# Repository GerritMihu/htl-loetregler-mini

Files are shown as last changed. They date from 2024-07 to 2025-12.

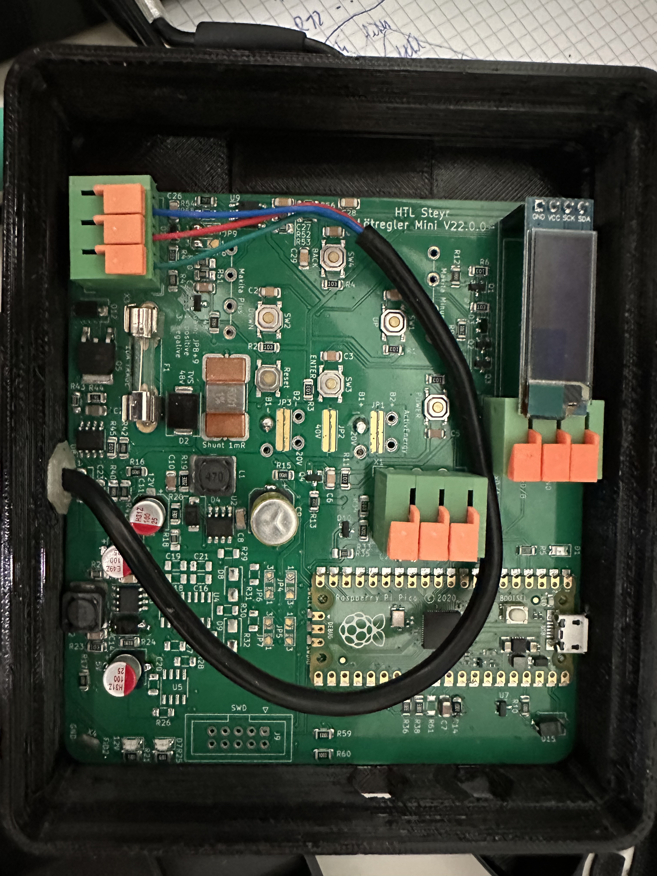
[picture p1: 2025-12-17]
arbeitsanweisungen/Kabel.jpeg

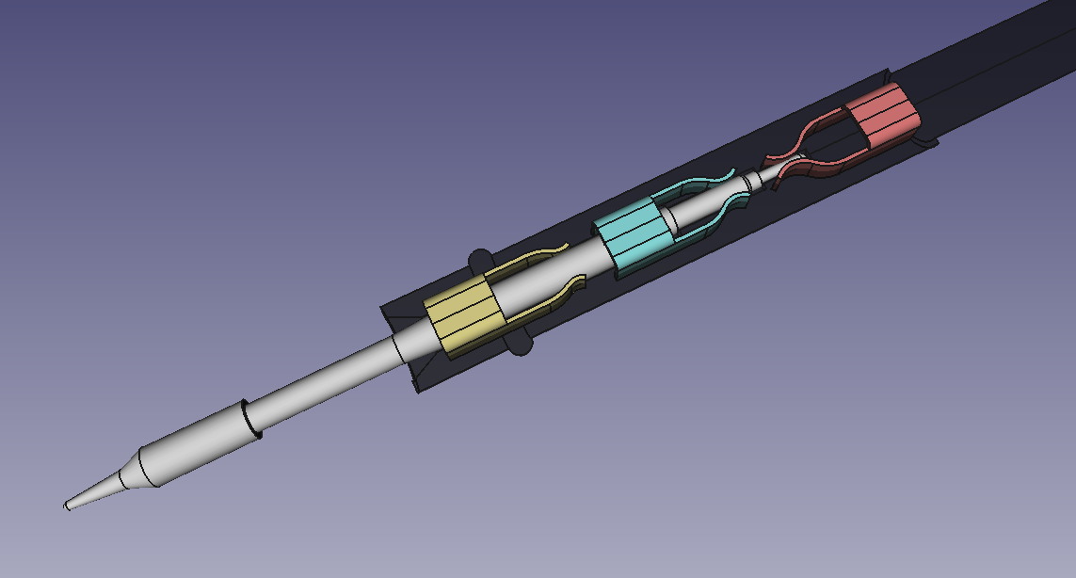
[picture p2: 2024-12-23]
3d/griffstück/screenshot griffstück v1.png

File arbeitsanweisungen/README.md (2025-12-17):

# Lötregler Arbeitsanweisungen

## Vorbereitung

1. Überblick
   1. Hardware
      1. Elektronik
      2. Mechanik
   2. Software
      1. Arduino IDE
      2. Libraries
      3. Das Programm Selbst
   3. Assembling
      1. Zusammenbau
      2. Funktionstest

## Hardware

### Elektronik

1. Stücklisten öffnen
2. Bauteile komissionieren / prüfen
   1. Mengen
   2. Art / Type
   3. Fehlteile
3. Siebdruck
   1. Drucken
   2. Sichtkontrolle / ggf reparatur
4. Bestückung
   1. Bestücken aller Bauteile laut Stückliste
      1. Polaritäten richtig
      2. Werte richtig
      3. Pin 1 bei IC's
   2. Sichtkontrolle / ggf reparatur
5. Reflow
   1. Richtige Temperatur eingestellt
   2. Richtige Temperatur erreicht
   3. Sichtkontrolle / ggf reparatur
6. Handlöten der THT Bauteile
   1. Bauteil bestücken
   2. Bauteil fixieren
   3. Bauteil mit Handlötkolben löten
   4. Sichtkontrolle / ggf reparatur
7. Stecken des Displays
8. Elektrische prüfung der Platine durchführen

### Mechanik

1. Entscheidung welche Variante des Gehäuses gefertigt wird
2. Öffnen der .STL oder .3MF mit einem Slicer
3. Slicen der Dateien als .GCODE
   1. Richtiger Kunststoff
   2. Richtiger Drucker
   3. Stützen an den richtigen Stellen?
   4. Lagenhöhe
   5. Druck Qualität / Geschwindigkeit
4. Transfer der .GCODE Datei auf den Drucker
5. Drucker vorbereiten
   1. Druckbett mit Wasser reinigen
   2. Klebestift auftragen, nur dort wo gedruckt wird
   3. Kunststoff richtig eingespannt
      1. keine Knoten in Fillament
      2. richtiger Kunstoff
      3. Rolle läuft frei / leichtgängig
6. Druck starten
   1. Erste Lage auf Offensichtliche Fehler inspizieren
7. Teile durch biegen des Druckbettes entfernen (Vorsicht heiß)
8. Druckbett reinigen
9. Stützen entfernen

## Software

1. Arduino IDE vorbereiten
   1. Libraries installieren
      1. Sketch ==> Bibliotek einbinden ==> Bibliothek verwalten
      2. Alle Libs aus der #Include einbinden
   2. MCU installieren
      1. Werkzeuge ==>  Board ==> Boardverwalter ==> Raspberry Pico RP2040
2. Code anpassen
   1. Namen Eintragen
   2. Software den eigenen Vorstellungen anpassen
3. Überprüfen drücken
   1. Fehler beheben
4. Leiterplatte mit PC verbinden
5. Upload drücken

## Assembling

1. Elektronik auf Grundplatte
2. Rahmen raufstecken
3. Akkuschuh anschweißen
4. Handstück vorbereiten
5. Hansstück anschließen
6. Zugentlastung
7. Betätiger für Taster einsetzen
8. Deckel montieren
9. Funktionstest mit Testlötspitzen
10. Leistungskalibrierung
11. Have fun...

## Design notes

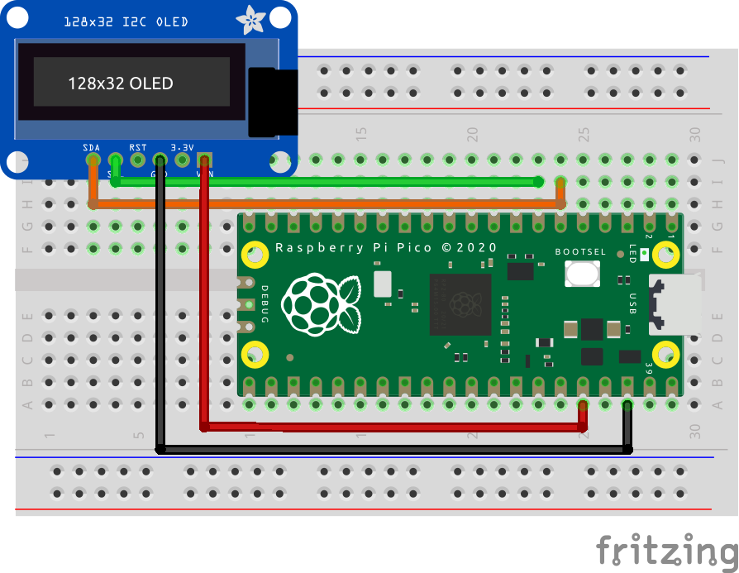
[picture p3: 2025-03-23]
arduino/RP2040/ssd1306_i2c/ssd1306_i2c_bb.png

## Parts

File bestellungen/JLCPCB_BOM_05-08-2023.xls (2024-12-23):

Comment | Designator | Footprint | JLCPCB Part#(optional)
100n/50V | C1 | C_1206_3216Metric | C464972
100n/50V | C2 | C_1206_3216Metric | C464972
100n/50V | C3 | C_1206_3216Metric | C464972
100n/50V | C4 | C_1206_3216Metric | C464972
100n/50V | C16 | C_1206_3216Metric | C464972
100n/50V | C17 | C_1206_3216Metric | C464972
100n/50V | C18 | C_1206_3216Metric | C464972
100n/50V | C19 | C_1206_3216Metric | C464972
100n/50V | C20 | C_1206_3216Metric | C464972
100n/50V | C21 | C_1206_3216Metric | C464972
100n/50V | C22 | C_1206_3216Metric | C464972
100n/50V | C25 | C_1206_3216Metric | C464972
100n/50V | C27 | C_1206_3216Metric | C464972
10n/50V | C6 | C_1206_3216Metric | C525316
10n/50V | C26 | C_1206_3216Metric | C525316
10n/50V | C28 | C_1206_3216Metric | C525316
10n/50V | C29 | C_1206_3216Metric | C525316
100u/25V | C11 | CP_Elec_6.3x5.9 | C320569
100u/25V | C13 | CP_Elec_6.3x5.9 | C320569
100u/25V | C15 | CP_Elec_6.3x5.9 | C320569
10u/16V | C7 | C_1206_3216Metric | C47971
10u/16V | C23 | C_1206_3216Metric | C47971
100n/100V | C8 | C_1206_3216Metric | C1945
100n/100V | C12 | C_1206_3216Metric | C1945
33n/50V | C10 | C_1206_3216Metric | C309052
33n/50V | C14 | C_1206_3216Metric | C309052
1n/100V | C5 | C_1206_3216Metric | C398254
100u/63V | C9 | CP_Elec_8x10 | C487384
1u/100V | C24 | C_1206_3216Metric | C70463
10k | R1 | R_1206_3216Metric | C118075
10k | R2 | R_1206_3216Metric | C118075
10k | R3 | R_1206_3216Metric | C118075
10k | R4 | R_1206_3216Metric | C118075
10k | R6 | R_1206_3216Metric | C118075
10k | R7 | R_1206_3216Metric | C118075
10k | R8 | R_1206_3216Metric | C118075
10k | R11 | R_1206_3216Metric | C118075
10k | R23 | R_1206_3216Metric | C118075
10k | R34 | R_1206_3216Metric | C118075
10k | R45 | R_1206_3216Metric | C118075
10k | R49 | R_1206_3216Metric | C118075
10k | R61 | R_1206_3216Metric | C118075
100R | R18 | R_1206_3216Metric | C245445
100R | R22 | R_1206_3216Metric | C245445
100R | R29 | R_1206_3216Metric | C245445
100R | R30 | R_1206_3216Metric | C245445
100R | R35 | R_1206_3216Metric | C245445
100R | R43 | R_1206_3216Metric | C245445
100R | R50 | R_1206_3216Metric | C245445
100R | R51 | R_1206_3216Metric | C245445
100R | R53 | R_1206_3216Metric | C245445
100R | R55 | R_1206_3216Metric | C245445
100R | R56 | R_1206_3216Metric | C245445
100R | R57 | R_1206_3216Metric | C245445
1k | R5 | R_1206_3216Metric | C104601
1k | R12 | R_1206_3216Metric | C104601
1k | R14 | R_1206_3216Metric | C104601
1k | R27 | R_1206_3216Metric | C104601
1k | R28 | R_1206_3216Metric | C104601
1k | R40 | R_1206_3216Metric | C104601
1k | R41 | R_1206_3216Metric | C104601
1k | R42 | R_1206_3216Metric | C104601
1k | R48 | R_1206_3216Metric | C104601
3k3 | R20 | R_1206_3216Metric | C137292
3k3 | R21 | R_1206_3216Metric | C137292
3k3 | R26 | R_1206_3216Metric | C137292
3k3 | R36 | R_1206_3216Metric | C137292
3k3 | R38 | R_1206_3216Metric | C137292
100k | R10 | R_1206_3216Metric | C269765
100k | R47 | R_1206_3216Metric | C269765
100k | R59 | R_1206_3216Metric | C269765
100k | R60 | R_1206_3216Metric | C269765
22k | R13 | R_1206_3216Metric | R3216-22k
22k | R52 | R_1206_3216Metric | R3216-22k
22k | R54 | R_1206_3216Metric | R3216-22k
1R | R15 | R_1206_3216Metric | C17928
1R | R16 | R_1206_3216Metric | C17928
1R | R17 | R_1206_3216Metric | C17928
10R | R31 | R_1206_3216Metric | R3216-10R
10R | R32 | R_1206_3216Metric | R3216-10R
2k7 | R9 | R_1206_3216Metric | C310343
30k | R19 | R_1206_3216Metric | C137314
6k2 | R24 | R_1206_3216Metric | C323110
680R | R25 | R_1206_3216Metric | C25392
82k | R33 | R_1206_3216Metric | C310365
56k | R44 | R_1206_3216Metric | R3216-56k
1mR/7W/1% | R46 | Shunt-15.2x7.6mm | C481499
47u/1A | L1 | L_7.3x7.3_H4.5_C216198 | C216198
47u/1A | L2 | L_7.3x7.3_H4.5_C216198 | C216198
SS210 | D4 | D_SMA_wide | C2683692
SS210 | D6 | D_SMA_wide | C2683692
SS210 | D11 | D_SMA_wide | C2683692
SS210 | D12 | D_SMA_wide | C2683692
SS210 | D15 | D_SMA_wide | C2683692
BAV99 | D10 | SOT-23 | C2886576
BAV99 | D13 | SOT-23 | C2886576
BAV99 | D14 | SOT-23 | C2886576
grün | D5 | LED_1206_3216Metric | C965825
grün | D7 | LED_1206_3216Metric | C965825
SMAJ8.0CA | D8 | D_SMA | C908814
SMAJ8.0CA | D9 | D_SMA | C908814
rot | D1 | LED_1206_3216Metric | C965823
SMCJ48A | D2 | D_SMC | C310056
3V3 | D3 | SOT-23 | C550950
XL7005A | U2 | SOIC-8-1EP_3.9x4.9mm_P1.27mm_EP2.514x3.2mm_ThermalVias | C50848
XL7005A | U3 | SOIC-8-1EP_3.9x4.9mm_P1.27mm_EP2.514x3.2mm_ThermalVias | C50848
OLED-128x32-Module | U1 | OLED-128x32 | OLED_128x64_white
MAX3232 | U4 | SOIC-16_3.9x9.9mm_P1.27mm | C434486
YD3082EESA | U5 | SOIC-8_3.9x4.9mm_P1.27mm | C269866
LM4040CIM3-3.0/NOPB | U7 | SOT-23 | C132056
TF2101M-TAH | U8 | SOIC-8_3.9x4.9mm_P1.27mm | C2683752
GS8332-SR | U9 | SOIC-8_3.9x4.9mm_P1.27mm | C157713
POWER | X1 | Federklemme_KF142_3P_P5.08mm_C475145 | C80054
COM | X2 | Federklemme_KF142_3P_P5.08mm_C475145 | C80054
Lötkolben | X3 | Federklemme_KF142_3P_P5.08mm_C475145 | C80054
GND-Öse | X4 | Keystone_5016 | C238129
Clip 20x5 | F1 | fuse-clip_20x5mm | C3130
UP | SW1 | SW_Push_5.1mm_H1.5mm | C318884
DOWN | SW2 | SW_Push_5.1mm_H1.5mm | C318884
ENTER | SW3 | SW_Push_5.1mm_H1.5mm | C318884
BACK | SW4 | SW_Push_5.1mm_H1.5mm | C318884
Ein/Aus | SW5 | SW_Push_5.1mm_H1.5mm | C318884
RESET | SW6 | SW_Push_5.1mm_H1.5mm | C318884
MMBT3904 | Q2 | SOT-23 | C382281
MMBT3904 | Q3 | SOT-23 | C382281
Buchsenleiste 4P | Item1 | Virtual-Item | C5176037
Clip 20x5 | Item4 | Virtual-Item | C3130
Sicherung, 5x20, 10A, träge | Item5 | Virtual-Item | C142673
2N7002 | Q1 | SOT-23 | C350313
ZXMP10A13FTA | Q4 | SOT-23 | C50185
KND3508A | Q5 | TO-252-2 | C116513
SWD | J9 | IDC-Header_2x05_P2.54mm_Vertical | C5665

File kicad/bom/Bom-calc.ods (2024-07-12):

null | Sourced | Placed | Inspected | References | Value | Footprint | Datasheet | Description | DistOrderNr | Distributor | Quantity
1 |  |  |  | C1, C2, C3, C4, C22, C25, C27 | 100n/50V | C_1206_3216Metric | https://datasheet.lcsc.com/szlcsc/1811151136_Walsin-Tech-Corp-0603B104K160CT_C80516.pdf |  | C464972 | LCSC | 7
2 |  |  |  | C6, C26, C28, C29 | 10n/50V | C_1206_3216Metric | https://datasheet.lcsc.com/lcsc/2006031834_PSA-Prosperity-Dielectrics-FN31X103K500PXG_C525316.pdf |  | C525316 | LCSC | 4
3 | ✓ |  |  | C11, C13, C15 | 100u/25V | CP_Elec_6.3x5.9 | https://datasheet.lcsc.com/lcsc/1810261549_AISHI-Aihua-Group-SVZ1EM101E06E00RAXXX_C320569.pdf |  | C320569 | LCSC | 3
4 | ✓ |  |  | C7, C23 | 10u/16V | C_1206_3216Metric | https://datasheet.lcsc.com/lcsc/1811151136_Samsung-Electro-Mechanics-CL31B106KOHNNNE_C47971.pdf |  | C47971 | LCSC | 2
5 |  |  |  | C8, C12 | 100n/100V | C_1206_3216Metric | https://datasheet.lcsc.com/lcsc/1810251120_Samsung-Electro-Mechanics-CL31B104KCFNNNE_C1945.pdf |  | C1945 | LCSC | 2
6 |  |  |  | C10, C14 | 33n/50V | C_1206_3216Metric | https://datasheet.lcsc.com/lcsc/1810261112_CCTC-TCC1206X7R333K500DT_C309052.pdf |  | C309052 | LCSC | 2
7 |  |  |  | C5 | 1n/100V | C_1206_3216Metric | https://datasheet.lcsc.com/lcsc/1912111437_IHHEC-HOLY-STONE-ENTERPRISE-CO---LTD-C1206X102K101T_C398254.pdf |  | C398254 | LCSC | 1
8 |  |  |  | C9 | 100u/63V | CP_Elec_8x10 | https://datasheet.lcsc.com/lcsc/2002201612_Ymin-VKMD1001J101MV_C487384.pdf |  | C487384 | LCSC | 1
9 |  |  |  | C24 | 1u/100V | C_1206_3216Metric | https://datasheet.lcsc.com/lcsc/1810241228_YAGEO-CC1206KKX7R0BB105_C70463.pdf |  | C70463 | LCSC | 1
10 |  |  |  | R1, R2, R3, R4, R6, R7, R8, R11, R23, R34, R45, R49 | 10k | R_1206_3216Metric | https://datasheet.lcsc.com/lcsc/1810301936_FH--Guangdong-Fenghua-Advanced-Tech-RS-06K103JT_C118075.pdf |  | C118075 | LCSC | 12
11 |  |  |  | R18, R22, R35, R43, R50, R51, R53, R55, R56, R57 | 100R | R_1206_3216Metric | https://datasheet.lcsc.com/lcsc/1811141436_Ever-Ohms-Tech-CR1206F100RP05Z_C245445.pdf |  | C245445 | LCSC | 10
12 |  |  |  | R5, R12, R14, R40, R41, R42, R48 | 1k | R_1206_3216Metric | https://datasheet.lcsc.com/lcsc/1811081842_RALEC-RTT06102JTP_C104601.pdf |  | C104601 | LCSC | 7
13 |  |  |  | R10, R47, R59, R60 | 100k | R_1206_3216Metric | https://datasheet.lcsc.com/lcsc/1811101612_TyoHM-RMC1206100K1-N_C269765.pdf |  | C269765 | LCSC | 4
14 |  |  |  | R20, R21, R36, R38 | 3k3 | R_1206_3216Metric | https://datasheet.lcsc.com/lcsc/1810241114_YAGEO-AC1206FR-073K3L_C229599.pdf |  | C137292 | LCSC | 4
15 |  |  |  | R13, R52, R54 | 22k | R_1206_3216Metric |  |  | R3216-22k | AufLager | 3
16 |  |  |  | R15, R16, R17 | 1R | R_1206_3216Metric | https://datasheet.lcsc.com/lcsc/2206010145_UNI-ROYAL-Uniroyal-Elec-1206W4F100KT5E_C17928.pdf |  | C17928 | LCSC | 3
17 |  |  |  | R9 | 2k7 | R_1206_3216Metric | https://datasheet.lcsc.com/lcsc/1810311325_FH--Guangdong-Fenghua-Advanced-Tech-RS-06K2701FT_C310343.pdf |  | C310343 | LCSC | 1
18 |  |  |  | R19 | 30k | R_1206_3216Metric | https://datasheet.lcsc.com/lcsc/1810241230_YAGEO-RC1206FR-0730KL_C137314.pdf |  | C137314 | LCSC | 1
19 |  |  |  | R24 | 6k2 | R_1206_3216Metric | https://datasheet.lcsc.com/lcsc/1912111437_FH--Guangdong-Fenghua-Advanced-Tech-RS-06K6191FT_C323110.pdf |  | C323110 | LCSC | 1
20 |  |  |  | R25 | 680R | R_1206_3216Metric | https://datasheet.lcsc.com/lcsc/1810311130_FH--Guangdong-Fenghua-Advanced-Tech-RS-06K681JT_C140005.pdf |  | C25392 | LCSC | 1
21 |  |  |  | R33 | 82k | R_1206_3216Metric | https://datasheet.lcsc.com/lcsc/1810311325_FH--Guangdong-Fenghua-Advanced-Tech-RS-06K8202FT_C310365.pdf |  | C310365 | LCSC | 1
22 |  |  |  | R44 | 56k | R_1206_3216Metric |  |  | R3216-56k | AufLager | 1
23 |  |  |  | R46 | 1mR/7W/1% | Shunt-15.2x7.6mm | https://datasheet.lcsc.com/lcsc/2001071408_Milliohm-HoLRS1575-1mR-1-_C481499.pdf |  | C481499 | LCSC | 1
24 |  |  |  | L1, L2 | 47u/1A | L_7.3x7.3_H4.5_C216198 | https://datasheet.lcsc.com/lcsc/1811131654_Sunltech-Tech-SLH0704S470MTT_C216198.pdf |  | C216198 | LCSC | 2
25 |  |  |  | D4, D6, D11, D12, D15 | SS210 | D_SMA_wide | https://datasheet.lcsc.com/lcsc/2101111838_ZHIDE-SS210A-W_C2683692.pdf |  | C2683692 | LCSC | 5
26 |  |  |  | D10, D13, D14 | BAV99 | SOT-23 | https://assets.nexperia.com/documents/data-sheet/BAV99_SER.pdf |  | C2886576 | LCSC | 3
27 |  |  |  | D5, D7 | grün | LED_1206_3216Metric | https://datasheet.lcsc.com/lcsc/2101041032_XINGLIGHT-XL-3216UGC_C965825.pdf |  | C965825 | LCSC | 2
28 |  |  |  | D1 | rot | LED_1206_3216Metric | https://datasheet.lcsc.com/lcsc/2101041032_XINGLIGHT-XL-3216UOC_C965823.pdf |  | C965823 | LCSC | 1
29 |  |  |  | D2 | SMCJ48A | D_SMC | https://datasheet.lcsc.com/lcsc/1912111437_Brightking-SMCJ48A-TR13_C310056.pdf |  | C310056 | LCSC | 1
30 |  |  |  | D3 | 3V3 | SOT-23 | https://diotec.com/tl_files/diotec/files/pdf/datasheets/bzx84c2v4.pdf |  | C550950 | LCSC | 1
31 |  |  |  | U2, U3 | XL7005A | SOIC-8-1EP_3.9x4.9mm_P1.27mm_EP2.514x3.2mm_ThermalVias | https://datasheet.lcsc.com/lcsc/1811081614_XLSEMI-XL7005A_C50848.pdf |  | C50848 | LCSC | 2
32 |  |  |  | U1 | OLED-128x32-Module | OLED-128x32 |  |  | OLED_128x64_white | AliExpress, SAMIORE Store | 1
33 |  |  |  | U6 | Pico | RPi_Pico_SMD |  |  |  |  | 1
34 |  |  |  | U7 | LM4040CIM3-3.0/NOPB | SOT-23 | http://www.ti.com/lit/ds/symlink/lm4040-n.pdf |  | C132056 | LCSC | 1
35 |  |  |  | U8 | TF2101M-TAH | SOIC-8_3.9x4.9mm_P1.27mm |  |  | C2683752 | LCSC | 1
36 |  |  |  | U9 | GS8332-SR | SOIC-8_3.9x4.9mm_P1.27mm | http://www.ti.com/lit/ds/symlink/lm2904-n.pdf |  | C157713 | LCSC | 1
37 |  |  |  | X1 | POWER | Federklemme_KF142_3P_P5.08mm_C475145 | https://datasheet.lcsc.com/lcsc/2001151504_Cixi-Kefa-Elec-KF142R-5-08-3P_C475145.pdf |  | C80054 | LCSC | 1
38 |  |  |  | X2 | COM | Federklemme_KF142_3P_P5.08mm_C475145 | https://datasheet.lcsc.com/lcsc/2001151504_Cixi-Kefa-Elec-KF142R-5-08-3P_C475145.pdf |  | C80054 | LCSC | 1
39 |  |  |  | X3 | Lötkolben | Federklemme_KF142_3P_P5.08mm_C475145 | https://datasheet.lcsc.com/lcsc/2001151504_Cixi-Kefa-Elec-KF142R-5-08-3P_C475145.pdf |  | C80054 | LCSC | 1
40 |  |  |  | X4 | GND-Öse | Keystone_5016 | https://datasheet.lcsc.com/lcsc/1810151521_Keystone-5016_C238129.pdf |  | C238129 | LCSC | 1
41 |  |  |  | F1 | Clip 20x5 | fuse-clip_20x5mm | https://datasheet.lcsc.com/lcsc/1808311724_Shenzhen-lanson-Elec-LS-502_C182320.pdf |  | C3130 | LCSC | 1
42 |  |  |  | SW1 | UP | SW_Push_5.1mm_H1.5mm | https://datasheet.lcsc.com/lcsc/2002271431_XKB-Connectivity-TS-1187A-B-A-B_C318884.pdf |  | C318884 | LCSC | 1
43 |  |  |  | SW2 | DOWN | SW_Push_5.1mm_H1.5mm | https://datasheet.lcsc.com/lcsc/2002271431_XKB-Connectivity-TS-1187A-B-A-B_C318884.pdf |  | C318884 | LCSC | 1
44 |  |  |  | SW3 | ENTER | SW_Push_5.1mm_H1.5mm | https://datasheet.lcsc.com/lcsc/2002271431_XKB-Connectivity-TS-1187A-B-A-B_C318884.pdf |  | C318884 | LCSC | 1
45 |  |  |  | SW4 | BACK | SW_Push_5.1mm_H1.5mm | https://datasheet.lcsc.com/lcsc/2002271431_XKB-Connectivity-TS-1187A-B-A-B_C318884.pdf |  | C318884 | LCSC | 1
46 |  |  |  | SW5 | Ein/Aus | SW_Push_5.1mm_H1.5mm | https://datasheet.lcsc.com/lcsc/2002271431_XKB-Connectivity-TS-1187A-B-A-B_C318884.pdf |  | C318884 | LCSC | 1
47 |  |  |  | SW6 | RESET | SW_Push_5.1mm_H1.5mm | https://datasheet.lcsc.com/lcsc/2002271431_XKB-Connectivity-TS-1187A-B-A-B_C318884.pdf |  | C318884 | LCSC | 1
48 |  |  |  | JP4, JP5, JP6, JP7 | COM | SolderJumper-3_P2.0mm_Open_TrianglePad1.0x1.5mm_NumberLabels |  |  | NAP | NAP | 4
49 |  |  |  | FID1, FID2 | Fiducial | paste-fiducial | NAP |  | NAP | NAP | 2
50 |  |  |  | JP1, JP3 | 20V | SolderJumper-2_2.2x8mm_Open |  |  | NAP | NAP | 2
51 |  |  |  | JP8, JP9 | OP-Polarität | SolderJumper-3_P2.0mm_Open_TrianglePad1.0x1.5mm_NumberLabels |  |  | NAP | NAP | 2
52 |  |  |  | Q2, Q3 | MMBT3904 | SOT-23 | https://www.fairchildsemi.com/datasheets/2N/2N3904.pdf |  | C382281 | LCSC | 2
53 |  |  |  | Item1 | Buchsenleiste 4P | Virtual-Item |  |  | C5176037 | LCSC | 1
54 |  |  |  | Item2 | Stencil, 120um, 25mm Rand, Edelstahl | Virtual-Item |  |  | Custom1 | Multi-CB | 1
55 |  |  |  | Item3 | PCB, 1 Layer, 35um Cu, 1.6mm, ca. 100x110 | Virtual-Item |  |  | Custom2 | Multi-CB | 1
56 |  |  |  | Item4 | Clip 20x5 | Virtual-Item |  |  | C3130 | LCSC | 1
57 |  |  |  | Item5 | Sicherung, 5x20, 10A, träge | Virtual-Item |  |  | C142673 | LCSC | 1
58 |  |  |  | JP2 | 40V | SolderJumper-2_2.2x8mm_Open |  |  | NAP | NAP | 1
59 |  |  |  | Q1 | 2N7002 | SOT-23 | https://www.fairchildsemi.com/datasheets/2N/2N7002.pdf |  | C350313 | LCSC | 1
60 |  |  |  | Q4 | ZXMP10A13FTA | SOT-23 | http://assets.nexperia.com/documents/data-sheet/BSS84.pdf |  | C50185 | LCSC | 1
61 |  |  |  | Q5 | KND3508A | TO-252-2 | https://datasheet.lcsc.com/lcsc/1811151428_KIA-Semicon-Tech-KND3508A_C116513.pdf |  | C116513 | LCSC | 1
62 |  |  |  | J3, J4 | Makita Plus | Faston_Tab_6.3mm_vertical |  |  | VT FS-P 6,35 | Reichelt | 2
63 |  |  |  | J5, J6 | Makita Minus | Faston_Tab_6.3mm_vertical |  |  | VT FS-P 6,35 | Reichelt | 2
64 |  |  |  | J1 | ActivEnergy B2+ | Faston_Tab_6.3mm_vertical |  |  | VT FS-P 6,35 | Reichelt | 1
65 |  |  |  | J2 | ActivEnergy B1+ | Faston_Tab_6.3mm_vertical |  |  | VT FS-P 6,35 | Reichelt | 1
66 |  |  |  | J7 | ActivEnergy B2- | Faston_Tab_6.3mm_vertical |  |  | VT FS-P 6,35 | Reichelt | 1
67 |  |  |  | J8 | ActivEnergy B1- | Faston_Tab_6.3mm_vertical |  |  | VT FS-P 6,35 | Reichelt | 1

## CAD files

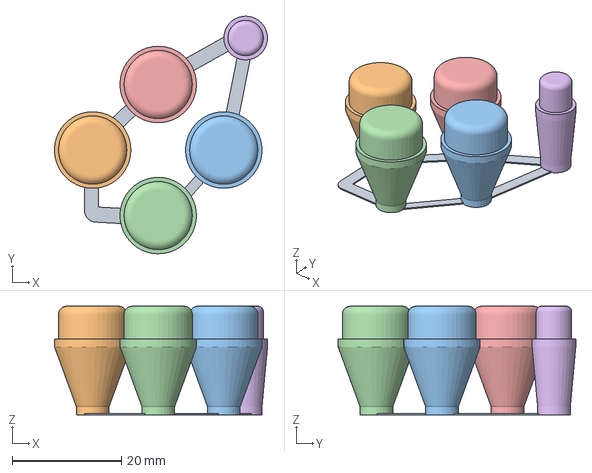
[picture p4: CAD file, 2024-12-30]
3d/gehäuse/Taster_ohne_reset.3mf
39.0 x 43.5 x 19.9 mm

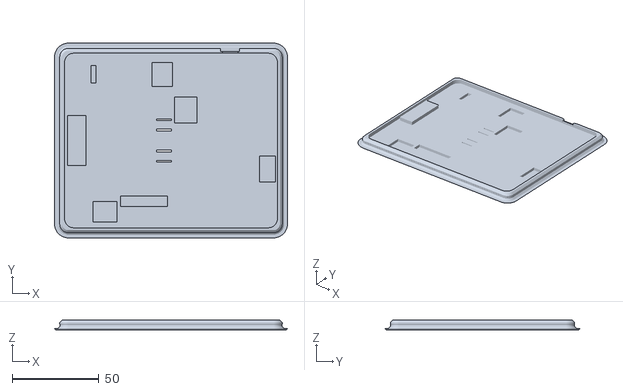
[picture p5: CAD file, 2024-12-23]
3d/gehäuse/lötregler-gehäuse-boden_v4_activEnergy.stl
134.0 x 112.0 x 5.80

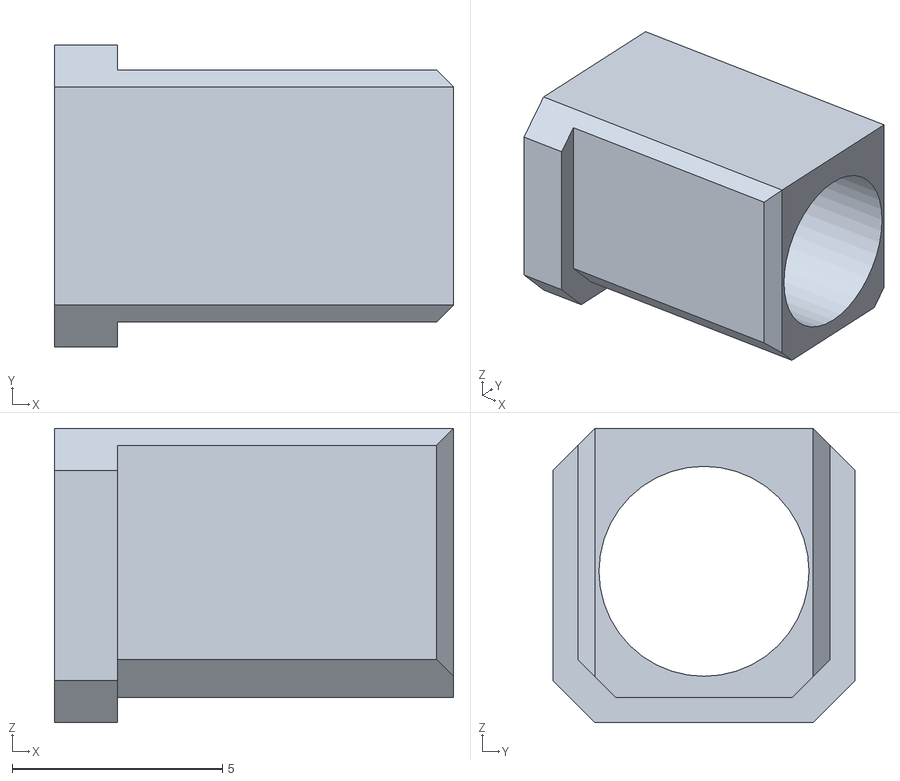
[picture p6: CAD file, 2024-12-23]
3d/griffstück/griffstück_isolator_htc-_h+_v2.2.stl
9.50 x 7.20 x 7.00

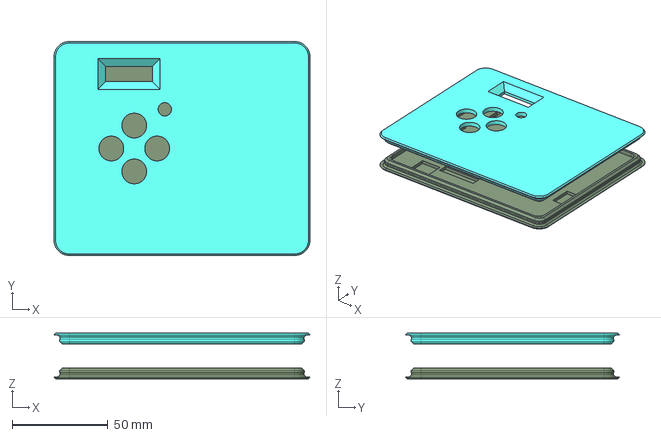
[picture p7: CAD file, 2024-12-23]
3d/gehäuse/lötregler-gehäuse.FCStd
134.0 x 112.0 x 24.0 mm
deckel_v3
Boden_ActivEnergy_v4

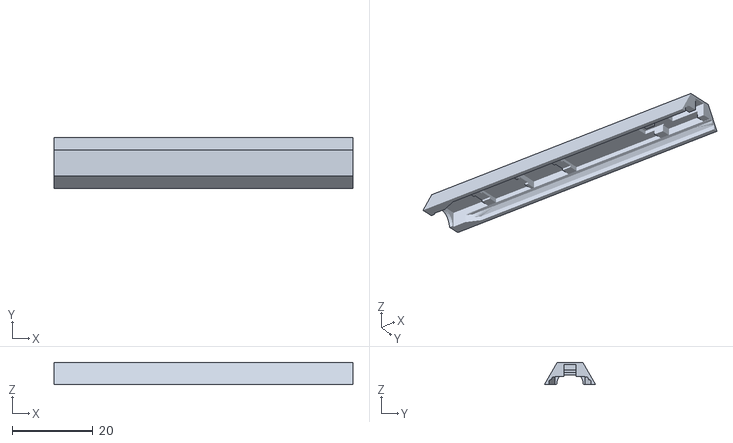
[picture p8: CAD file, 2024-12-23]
3d/griffstück/griffstück_halbschale-hex_v2.stl
74.0 x 12.7 x 5.50

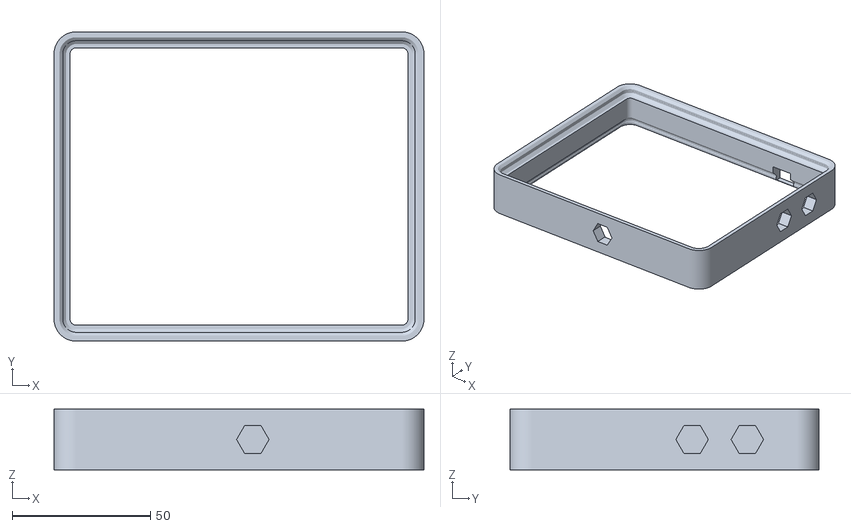
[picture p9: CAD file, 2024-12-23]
3d/gehäuse/lötregler-gehäuse-wand_v3.stl
134.0 x 112.0 x 22.0

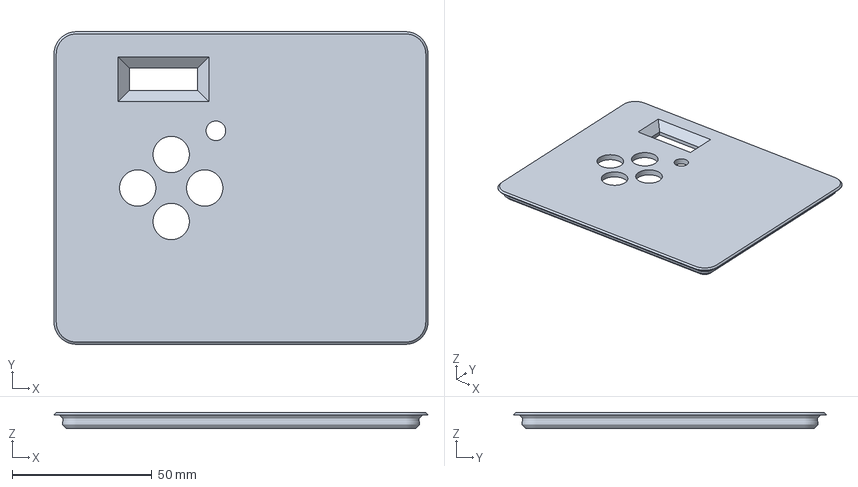
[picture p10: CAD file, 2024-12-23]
3d/gehäuse/Deckel_ohne_reset.3mf
134.0 x 112.0 x 5.80 mm

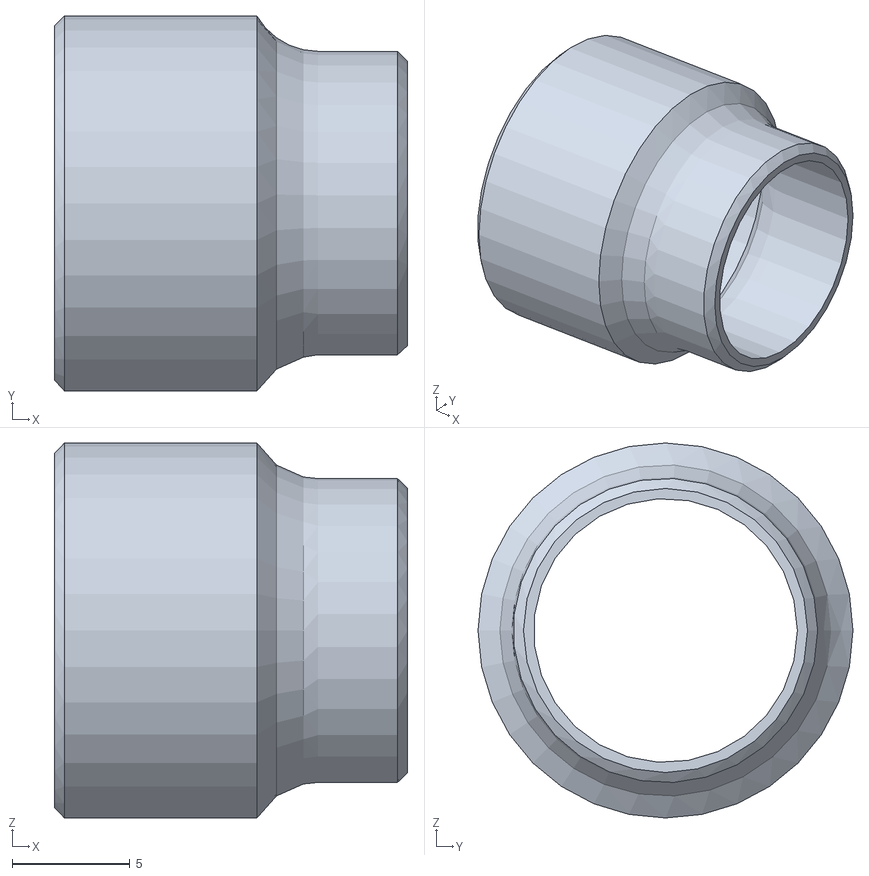
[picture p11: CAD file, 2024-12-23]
3d/griffstück/mittenring_v2.1.stl
15.0 x 15.9 x 15.9

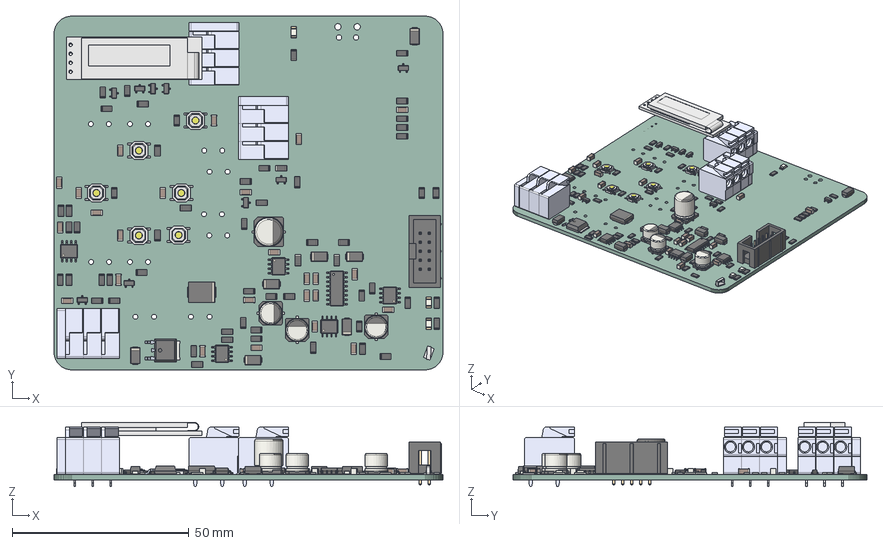
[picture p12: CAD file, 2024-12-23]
3d/gehäuse/jbc-miniregler.step
110.0 x 100.0 x 18.2 mm
PCB

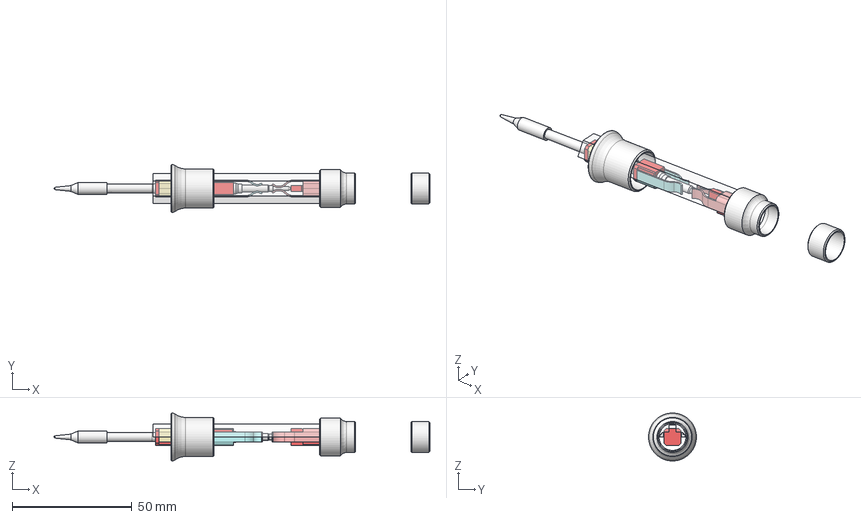
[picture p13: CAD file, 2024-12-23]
3d/griffstück/griffstück_v2.FCStd
156.8 x 20.0 x 20.0 mm
JBC-2245-003
Federkontakt_HTC-
Federkontakt_H+
Federkontakt_TC+
Fingerkuppenring_v2.1
Mittenring_v2
Endring_v2
Isolator_H+
Isolator_HTC-
Isolator_TC+
Halbschale-hex1

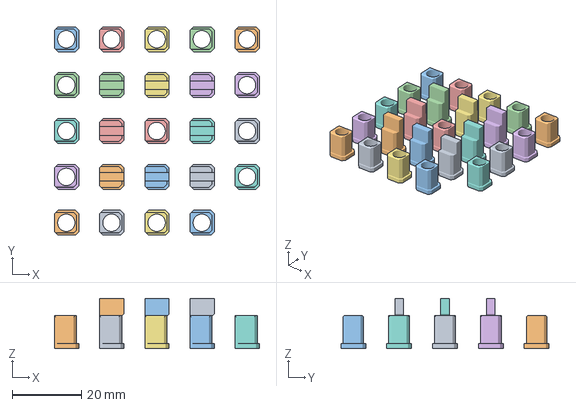
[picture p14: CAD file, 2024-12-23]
3d/griffstück/griffstück_isolatoren_v2.2 (perfektes ergebnis).3mf
59.0 x 60.0 x 14.5 mm
griffstück_isolator_htc-_h+_v2.2.stl
griffstück_isolator_tc+.stl

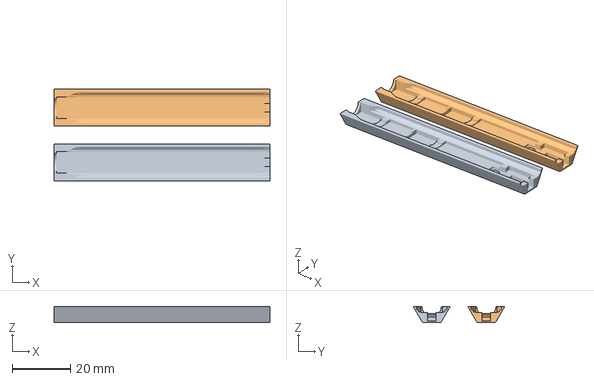
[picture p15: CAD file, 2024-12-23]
3d/griffstück/griffstück_halbschale-hex_v2_Polycarbonat.3mf
74.0 x 31.4 x 5.50 mm

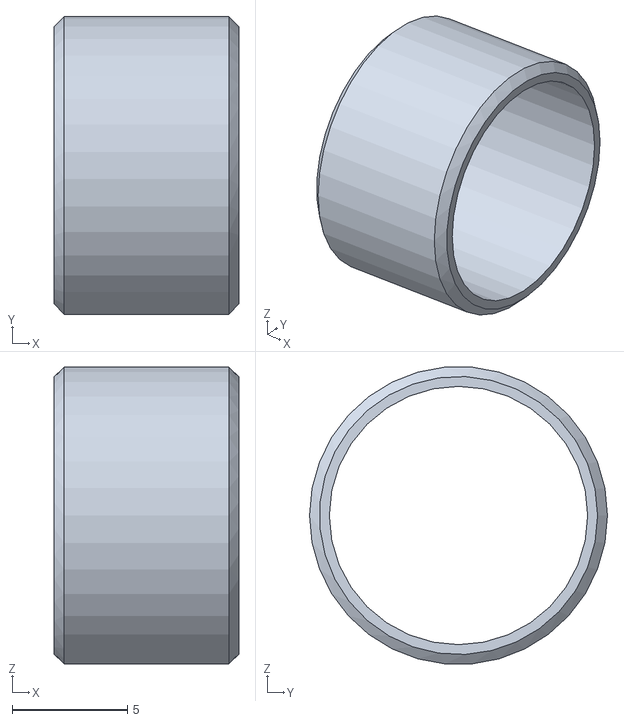
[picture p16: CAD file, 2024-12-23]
3d/griffstück/endring_v2.1.stl
8.00 x 12.9 x 12.9

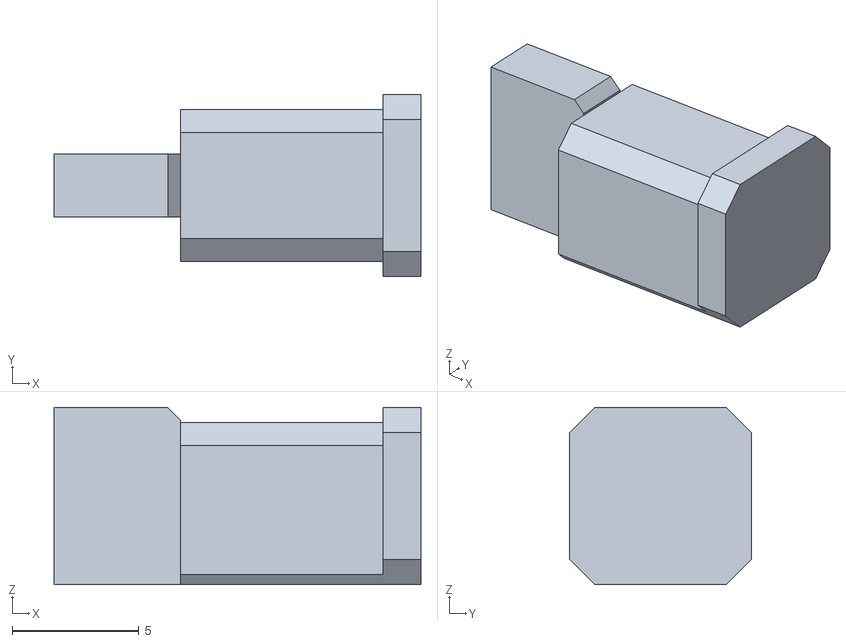
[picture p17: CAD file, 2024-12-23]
3d/griffstück/griffstück_isolator_tc+.stl
14.5 x 7.20 x 7.00

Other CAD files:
3d/gehäuse/lötregler-gehäuse-deckel_v3.stl
3d/gehäuse/makita_boden_v5.stl
3d/griffstück/griffstück_unten_v0.0.4.stl
3d/griffstück/griffstück_halbschale-rund_v2_Polycarbonat.3mf
3d/gehäuse/Old/blindstopfen_v1.3mf
3d/gehäuse/Old/gehäuse-boden_v0.stl
3d/gehäuse/Old/lötregler-gehäuse-boden_v1.stl
3d/gehäuse/Old/lötregler-gehäuse-boden_v2.stl
3d/gehäuse/Old/lötregler-gehäuse-boden_v3_activEnergy.stl
3d/gehäuse/Old/lötregler-gehäuse-deckel+wand_v1.3mf
3d/gehäuse/Old/lötregler-gehäuse-deckel_v1.stl
3d/gehäuse/Old/lötregler-gehäuse-deckel_v2.stl
3d/gehäuse/Old/lötregler-gehäuse-deckel_v3.stl
3d/gehäuse/Old/lötregler-gehäuse-wand_v1.stl
3d/gehäuse/Old/lötregler-gehäuse-wand_v2.3mf
3d/gehäuse/Old/lötregler-gehäuse-wand_v2.stl
3d/gehäuse/Old/taster_v2.stl
3d/gehäuse/Old/zugentlastung_v1.1.stl
3d/gehäuse/Old/zugentlastung_v1.2.stl
3d/gehäuse/Old/zugentlastung_v1.3.3mf
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

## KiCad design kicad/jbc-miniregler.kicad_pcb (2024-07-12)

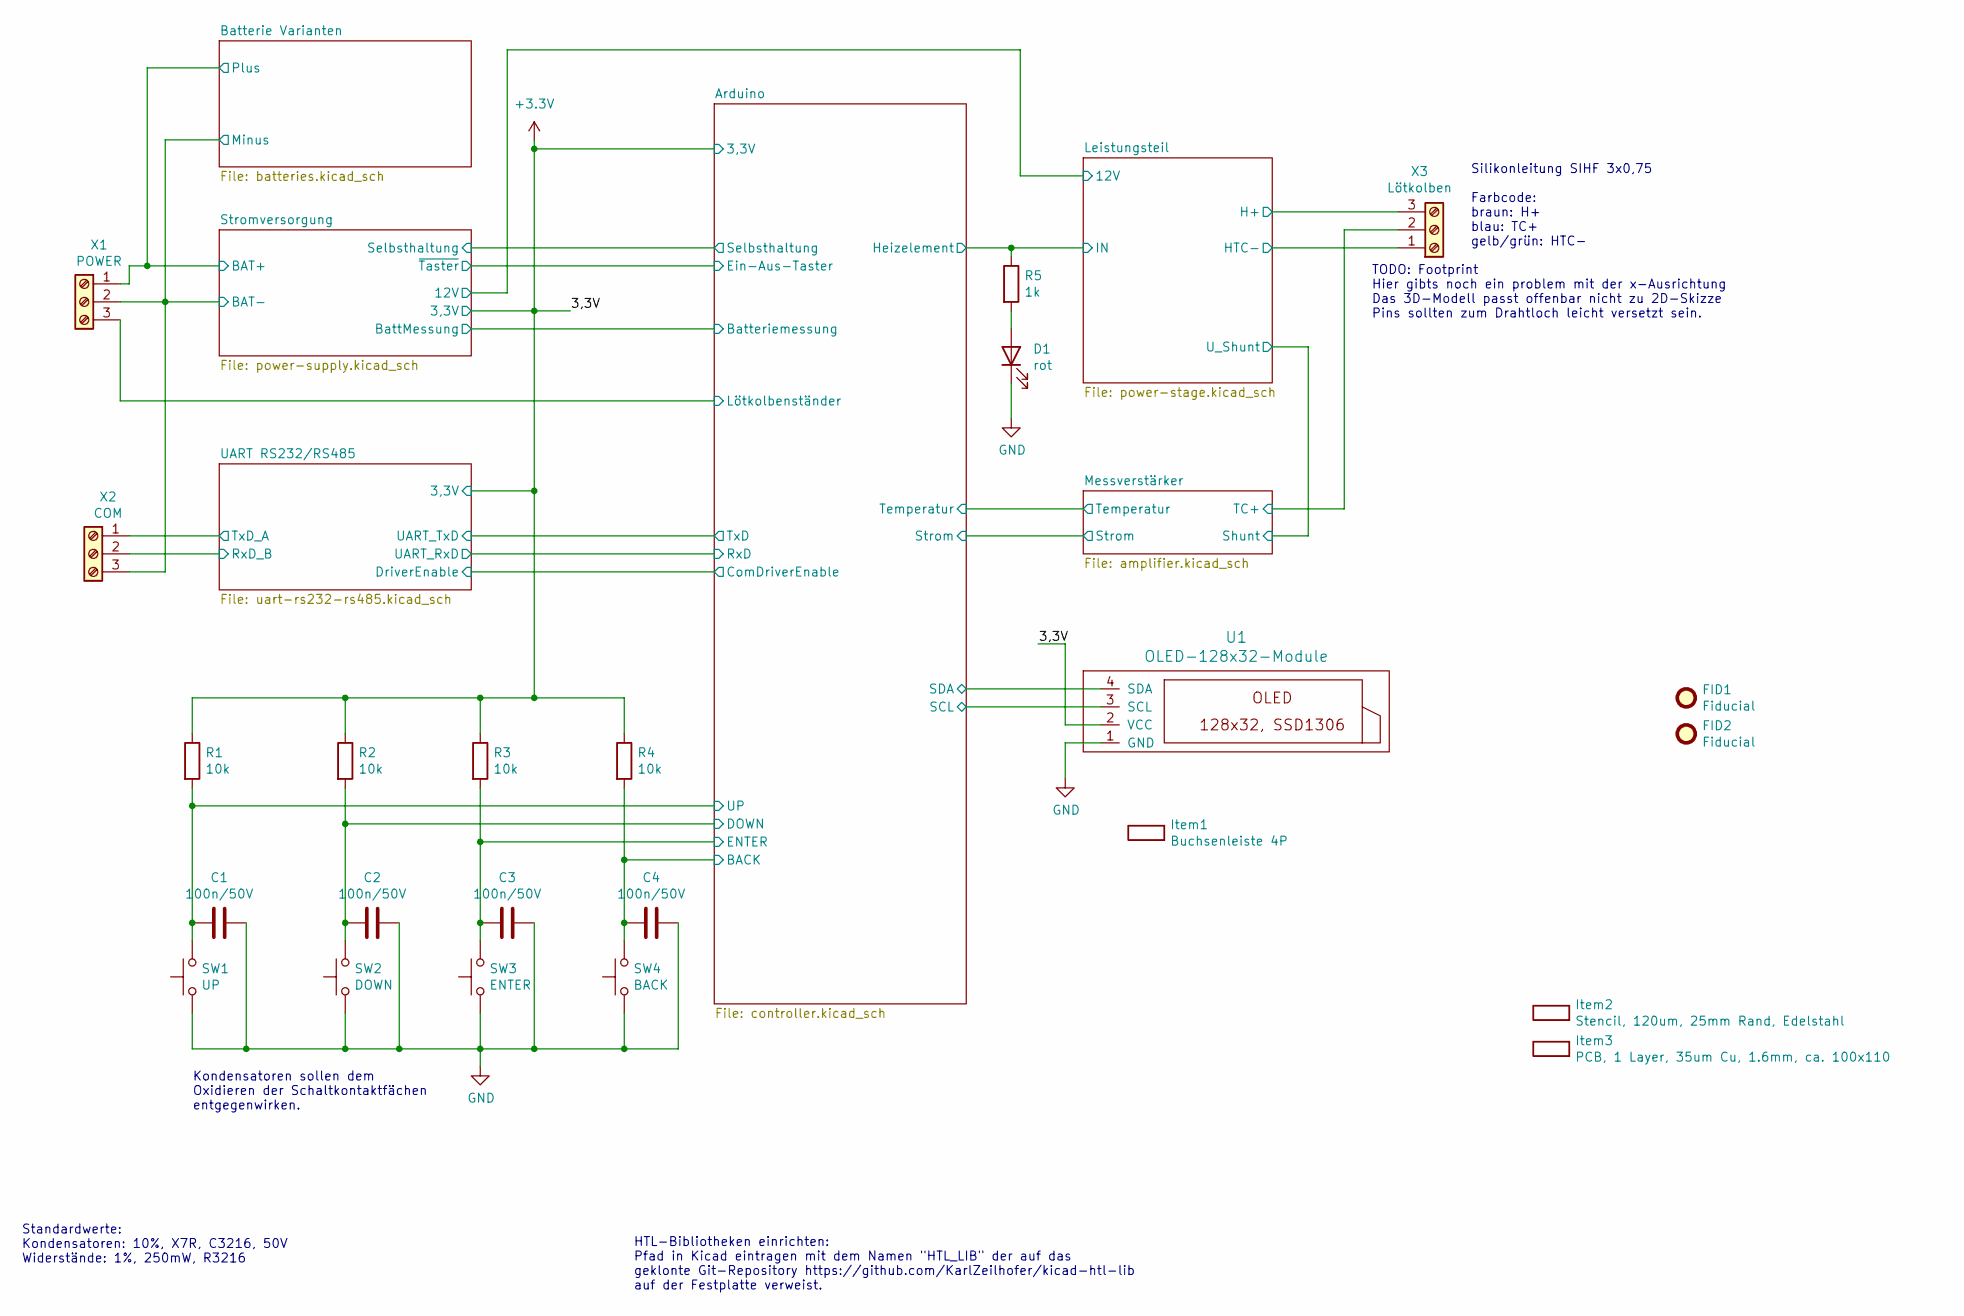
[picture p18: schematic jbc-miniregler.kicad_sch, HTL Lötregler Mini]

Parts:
C1, C2, C3, C4: 100n/50V; C_1206_3216Metric; ManPartNr FN31X104K500PXG
D1: rot; LED_1206_3216Metric; ManPartNr XL-3216UOC
FID1, FID2: Fiducial; paste-fiducial; ManPartNr NAP
Item1: Buchsenleiste 4P; Virtual-Item; ManPartNr A2541HWV-4P
Item2: Stencil, 120um, 25mm Rand, Edelstahl; Virtual-Item
Item3: PCB, 1 Layer, 35um Cu, 1.6mm, ca. 100x110; Virtual-Item
R1, R2, R3, R4: 10k; R_1206_3216Metric; ManPartNr RS-06K103JT
R5: 1k; R_1206_3216Metric; ManPartNr RTT03101JTP
SW1: UP; SW_Push_5.1mm_H1.5mm; ManPartNr TS-1187A-B-A-B
SW2: DOWN; SW_Push_5.1mm_H1.5mm; ManPartNr TS-1187A-B-A-B
SW3: ENTER; SW_Push_5.1mm_H1.5mm; ManPartNr TS-1187A-B-A-B
SW4: BACK; SW_Push_5.1mm_H1.5mm; ManPartNr TS-1187A-B-A-B
U1: OLED-128x32-Module; OLED-128x32
X1: POWER; Federklemme_KF142_3P_P5.08mm_C475145; ManPartNr KF142R-5.08-3P
X2: COM; Federklemme_KF142_3P_P5.08mm_C475145; ManPartNr KF142R-5.08-3P
X3: Lötkolben; Federklemme_KF142_3P_P5.08mm_C475145; ManPartNr KF142R-5.08-3P

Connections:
+3.3V: R1.1, R2.1, R3.1, R4.1, U1.2 (VCC); also elsewhere on the board
/Arduino/BACK: C4.2, R4.2, SW4.2; also elsewhere on the board
/Arduino/DOWN: C2.2, R2.2, SW2.2; also elsewhere on the board
/Arduino/ENTER: C3.2, R3.2, SW3.2; also elsewhere on the board
/Arduino/Heizelement: R5.1; also elsewhere on the board
/Arduino/Lötkolbenständer: X1.3; also elsewhere on the board
/Arduino/SCL: U1.3 (SCL); also elsewhere on the board
/Arduino/SDA: U1.4 (SDA); also elsewhere on the board
/Arduino/UP: C1.2, R1.2, SW1.2; also elsewhere on the board
/Batterie Varianten/Plus: X1.1; also elsewhere on the board
/Leistungsteil/H+: X3.3; also elsewhere on the board
/Leistungsteil/HTC-: X3.1; also elsewhere on the board
/Messverstärker/TC+: X3.2; also elsewhere on the board
/UART RS232/RS485/RxD_B: X2.2; also elsewhere on the board
/UART RS232/RS485/TxD_A: X2.1; also elsewhere on the board
GND: C1.1, C2.1, C3.1, C4.1, D1.1 (K), SW1.1, SW2.1, SW3.1, SW4.1, U1.1 (GND); also elsewhere on the board
GNDPWR: X1.2, X2.3; also elsewhere on the board
unnamed: D1.2 (A), R5.2

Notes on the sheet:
TODO: Footprint Hier gibts noch ein problem mit der x-Ausrichtung Das 3D-Modell passt offenbar nicht zu 2D-Skizze Pins sollten zum Drahtloch leicht versetzt sein.
Standardwerte: Kondensatoren: 10%, X7R, C3216, 50V Widerstände: 1%, 250mW, R3216
HTL-Bibliotheken einrichten: Pfad in Kicad eintragen mit dem Namen "HTL_LIB" der auf das geklonte Git-Repository https://github.com/KarlZeilhofer/kicad-htl-lib auf der Festplatte verweist.
Silikonleitung SIHF 3x0,75 Farbcode: braun: H+ blau: TC+ gelb/grün: HTC-
Kondensatoren sollen dem Oxidieren der Schaltkontaktfächen entgegenwirken.

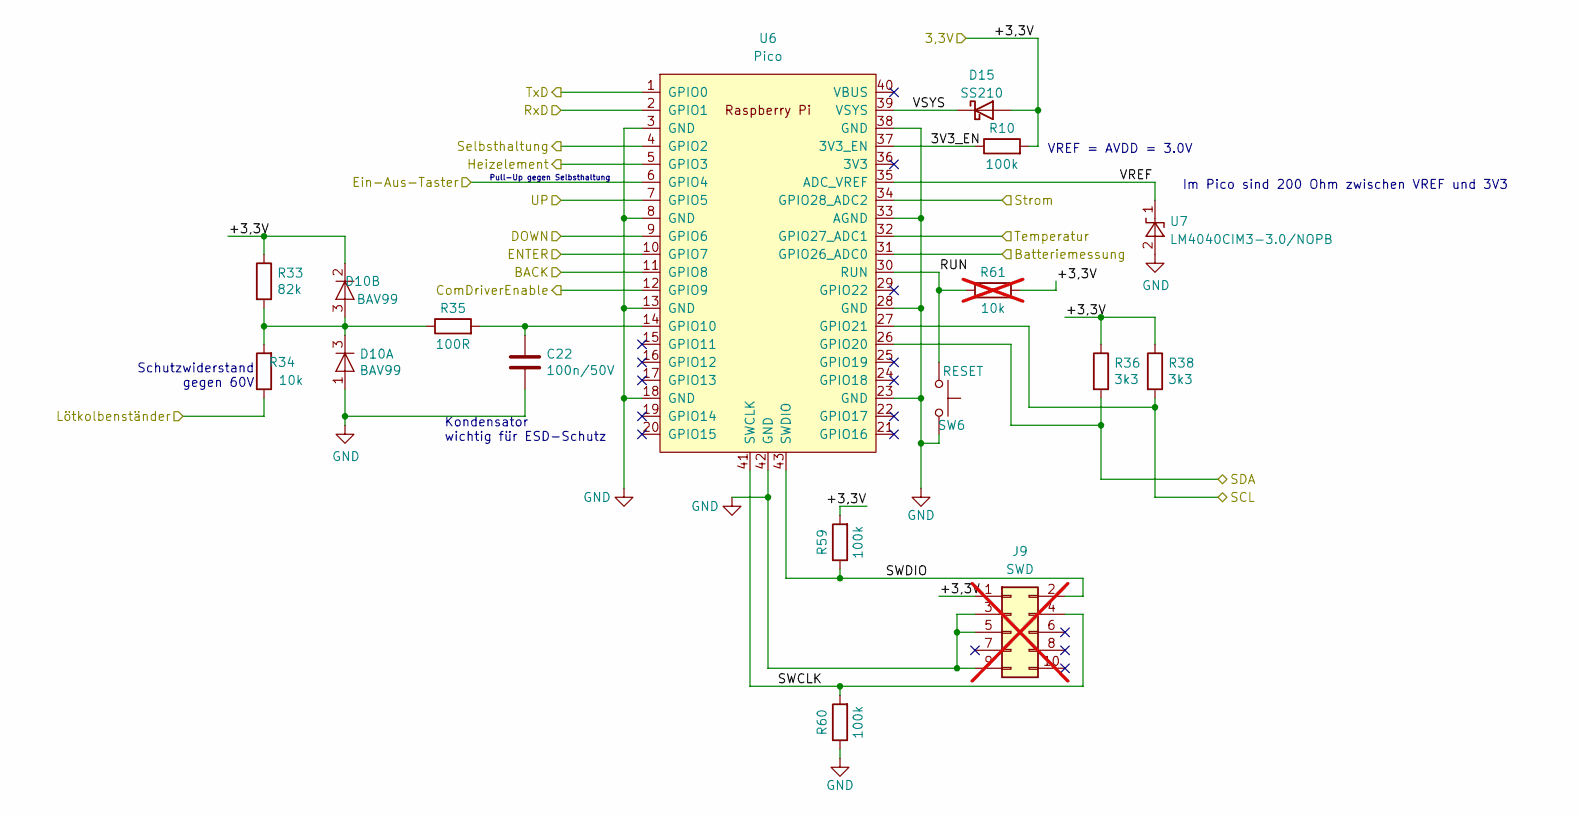
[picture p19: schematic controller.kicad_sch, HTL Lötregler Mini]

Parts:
C22: 100n/50V; C_1206_3216Metric; ManPartNr FN31X104K500PXG
D10: BAV99; SOT-23; ManPartNr BAV99
D15: SS210; D_SMA_wide; ManPartNr SS210A-W
J9: SWD; IDC-Header_2x05_P2.54mm_Vertical; ManPartNr C5665; not fitted
R10, R59, R60: 100k; R_1206_3216Metric; ManPartNr RMC1206100K1%N
R33: 82k; R_1206_3216Metric; ManPartNr RS-06K8202FT
R34: 10k; R_1206_3216Metric; ManPartNr RS-06K103JT
R35: 100R; R_1206_3216Metric; ManPartNr CR1206F100RP05Z
R36, R38: 3k3; R_1206_3216Metric; ManPartNr AC1206FR-073K3L
R61: 10k; R_1206_3216Metric; ManPartNr RS-06K103JT; not fitted
SW6: RESET; SW_Push_5.1mm_H1.5mm; ManPartNr TS-1187A-B-A-B
U6: Pico; RPi_Pico_SMD
U7: LM4040CIM3-3.0/NOPB; SOT-23

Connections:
+3.3V: D10.2 (K), D15.2 (A), J9.1, R10.2, R33.1, R36.1, R38.1, R59.2, R61.1; also elsewhere on the board
/Arduino/3V3_EN: R10.1, U6.37 (3V3_EN)
/Arduino/BACK: U6.11 (GPIO8); also elsewhere on the board
/Arduino/Batteriemessung: U6.31 (GPIO26_ADC0); also elsewhere on the board
/Arduino/ComDriverEnable: U6.12 (GPIO9); also elsewhere on the board
/Arduino/DOWN: U6.9 (GPIO6); also elsewhere on the board
/Arduino/ENTER: U6.10 (GPIO7); also elsewhere on the board
/Arduino/Ein-Aus-Taster: U6.6 (GPIO4); also elsewhere on the board
/Arduino/Heizelement: U6.5 (GPIO3); also elsewhere on the board
/Arduino/Lötkolbenständer: R34.1; also elsewhere on the board
/Arduino/RUN: R61.2, SW6.1, U6.30 (RUN)
/Arduino/RxD: U6.2 (GPIO1); also elsewhere on the board
/Arduino/SCL: R38.2, U6.27 (GPIO21); also elsewhere on the board
/Arduino/SDA: R36.2, U6.26 (GPIO20); also elsewhere on the board
/Arduino/SWCLK: J9.4, R60.2, U6.41 (SWCLK)
/Arduino/SWDIO: J9.2, R59.1, U6.43 (SWDIO)
/Arduino/Selbsthaltung: U6.4 (GPIO2); also elsewhere on the board
/Arduino/Strom: U6.34 (GPIO28_ADC2); also elsewhere on the board
/Arduino/Temperatur: U6.32 (GPIO27_ADC1); also elsewhere on the board
/Arduino/TxD: U6.1 (GPIO0); also elsewhere on the board
/Arduino/UP: U6.7 (GPIO5); also elsewhere on the board
/Arduino/VREF: U6.35 (ADC_VREF), U7.1 (K)
/Arduino/VSYS: D15.1 (K), U6.39 (VSYS)
GND: C22.2, D10.1 (A), J9.3, J9.5, J9.9, R60.1, SW6.2, U6.3 (GND), U6.8 (GND), U6.13 (GND), U6.18 (GND), U6.23 (GND), U6.28 (GND), U6.33 (AGND), U6.38 (GND), U6.42 (GND), U7.2 (A); also elsewhere on the board
unnamed: D10.3 (A), R33.2, R34.2, R35.1
unnamed: C22.1, R35.2, U6.14 (GPIO10)

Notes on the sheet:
VREF = AVDD = 3.0V
Pull-Up gegen Selbsthaltung
Im Pico sind 200 Ohm zwischen VREF und 3V3
Kondensator wichtig für ESD-Schutz
Schutzwiderstand gegen 60V

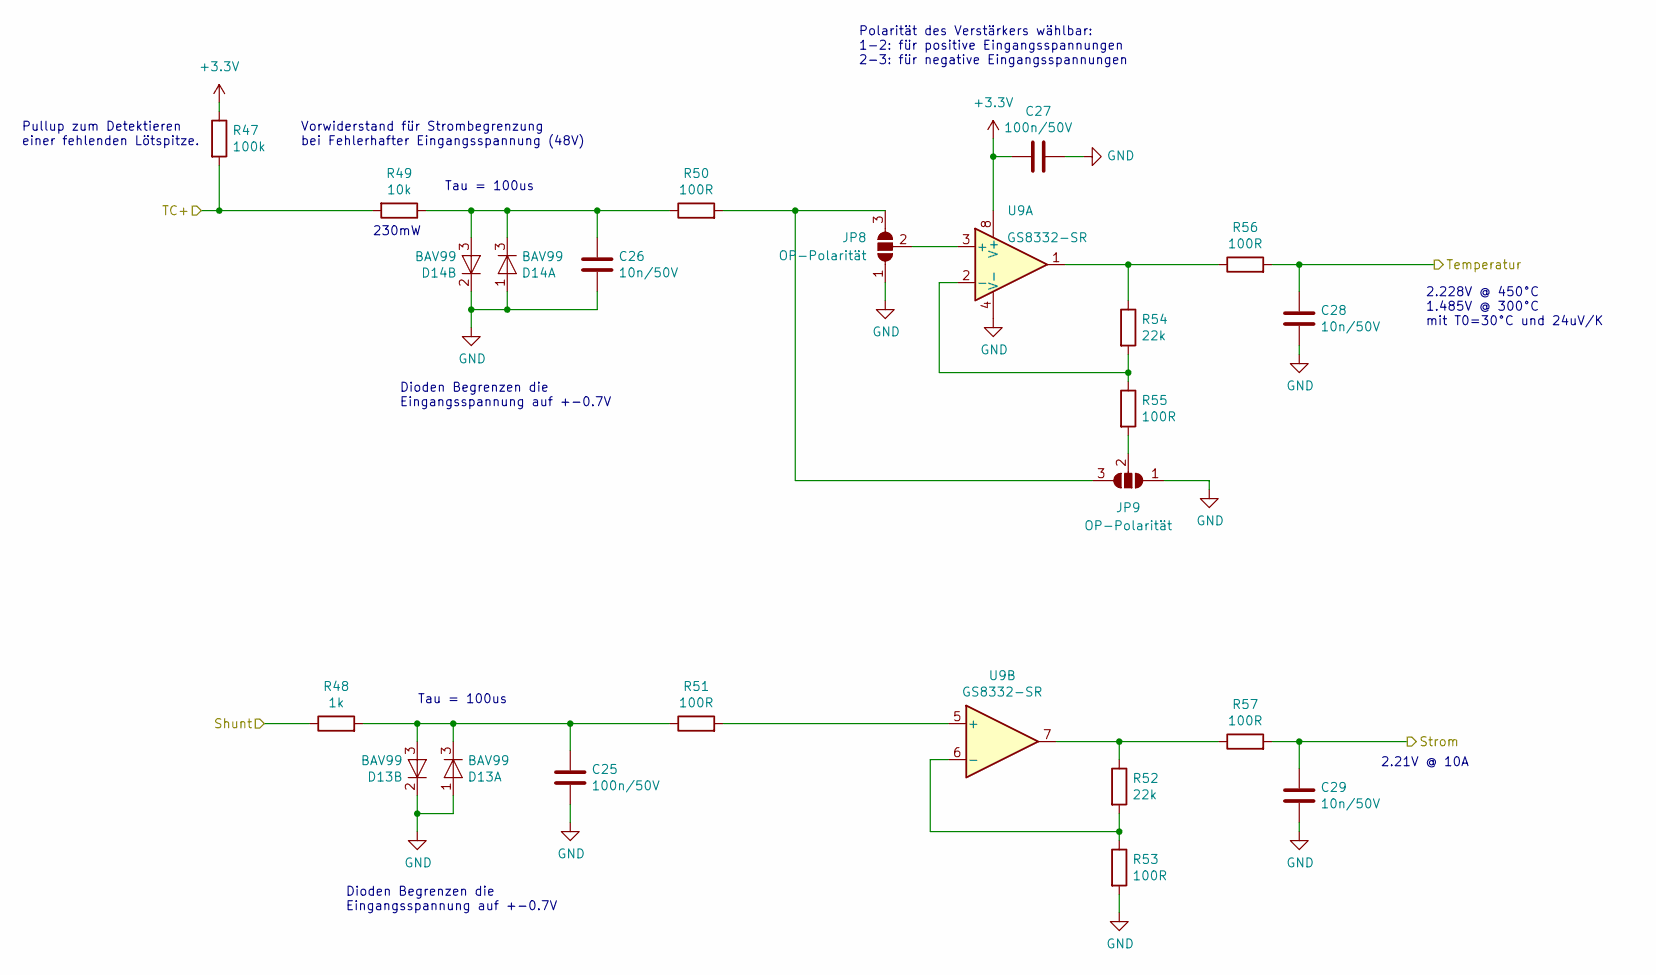
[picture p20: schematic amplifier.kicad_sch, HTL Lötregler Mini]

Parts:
C25, C27: 100n/50V; C_1206_3216Metric; ManPartNr FN31X104K500PXG
C26, C28, C29: 10n/50V; C_1206_3216Metric; ManPartNr FN31X103K500PXG
D13, D14: BAV99; SOT-23; ManPartNr BAV99
JP8, JP9: OP-Polarität; SolderJumper-3_P2.0mm_Open_TrianglePad1.0x1.5mm_NumberLabels; ManPartNr NAP
R47: 100k; R_1206_3216Metric; ManPartNr RMC1206100K1%N
R48: 1k; R_1206_3216Metric; ManPartNr RTT03101JTP
R49: 10k; R_1206_3216Metric; ManPartNr RS-06K103JT
R50, R51, R53, R55, R56, R57: 100R; R_1206_3216Metric; ManPartNr CR1206F100RP05Z
R52, R54: 22k; R_1206_3216Metric
U9: GS8332-SR; SOIC-8_3.9x4.9mm_P1.27mm; ManPartNr GS8332-SR

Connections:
+3.3V: C27.2, R47.1, U9.8 (V+); also elsewhere on the board
/Arduino/Strom: C29.1, R57.2; also elsewhere on the board
/Arduino/Temperatur: C28.1, R56.2; also elsewhere on the board
/Leistungsteil/U_Shunt: R48.1; also elsewhere on the board
/Messverstärker/TC+: R47.2, R49.2; also elsewhere on the board
GND: C25.1, C26.2, C27.1, C28.2, C29.2, D13.1 (A), D13.2 (K), D14.1 (A), D14.2 (K), JP8.1 (A), JP9.1 (A), R53.2, U9.4 (V-); also elsewhere on the board
unnamed: C25.2, D13.3 (A), R48.2, R51.1
unnamed: C26.1, D14.3 (K), R49.1, R50.1
unnamed: JP8.3 (B), JP9.3 (B), R50.2
unnamed: JP8.2 (C), U9.3 (+)
unnamed: JP9.2 (C), R55.2
unnamed: R52.1, R57.1, U9.7
unnamed: R54.1, R56.1, U9.1
unnamed: R54.2, R55.1, U9.2 (-)
unnamed: R51.2, U9.5 (+)
unnamed: R52.2, R53.1, U9.6 (-)

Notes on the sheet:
Dioden Begrenzen die Eingangsspannung auf +-0.7V
230mW
Tau = 100us
Vorwiderstand für Strombegrenzung bei Fehlerhafter Eingangsspannung (48V)
Pullup zum Detektieren einer fehlenden Lötspitze.
Polarität des Verstärkers wählbar: 1-2: für positive Eingangsspannungen 2-3: für negative Eingangsspannungen
2.228V @ 450°C 1.485V @ 300°C mit T0=30°C und 24uV/K
2.21V @ 10A

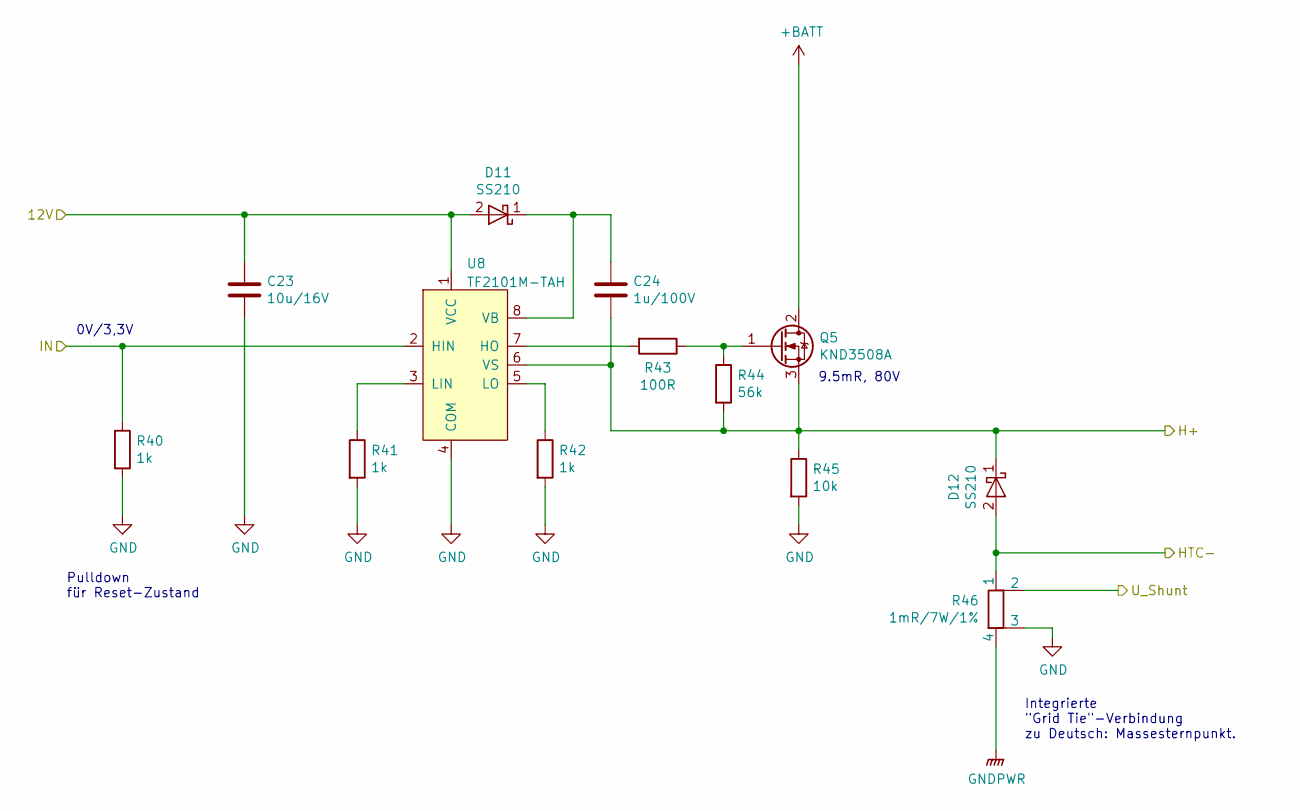
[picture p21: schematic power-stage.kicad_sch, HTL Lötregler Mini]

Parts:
C23: 10u/16V; C_1206_3216Metric; ManPartNr CL31B106KOHNNNE
C24: 1u/100V; C_1206_3216Metric; ManPartNr CC1206KKX7R0BB105
D11, D12: SS210; D_SMA_wide; ManPartNr SS210A-W
Q5: KND3508A; TO-252-2; ManPartNr KND3508A
R40, R41, R42: 1k; R_1206_3216Metric; ManPartNr RTT03101JTP
R43: 100R; R_1206_3216Metric; ManPartNr CR1206F100RP05Z
R44: 56k; R_1206_3216Metric
R45: 10k; R_1206_3216Metric; ManPartNr RS-06K103JT
R46: 1mR/7W/1%; Shunt-15.2x7.6mm; ManPartNr HoLRS1575-1mR-1%
U8: TF2101M-TAH; SOIC-8_3.9x4.9mm_P1.27mm; ManPartNr -nicht mehr aktuell?

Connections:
+BATT: Q5.2 (D); also elsewhere on the board
/Arduino/Heizelement: R40.1, U8.2 (HIN); also elsewhere on the board
/Leistungsteil/12V: C23.1, D11.2 (A), U8.1 (VCC); also elsewhere on the board
/Leistungsteil/H+: C24.2, D12.1 (K), Q5.3 (S), R44.2, R45.1, U8.6 (VS); also elsewhere on the board
/Leistungsteil/HTC-: D12.2 (A), R46.1; also elsewhere on the board
/Leistungsteil/U_Shunt: R46.2; also elsewhere on the board
GND: C23.2, R40.2, R41.2, R42.2, R45.2, R46.3, U8.4 (COM); also elsewhere on the board
GNDPWR: R46.4; also elsewhere on the board
unnamed: C24.1, D11.1 (K), U8.8 (VB)
unnamed: Q5.1 (G), R43.1, R44.1
unnamed: R43.2, U8.7 (HO)
unnamed: R41.1, U8.3 (LIN)
unnamed: R42.1, U8.5 (LO)

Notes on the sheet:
Integrierte "Grid Tie"-Verbindung zu Deutsch: Massesternpunkt.
9.5mR, 80V
Pulldown für Reset-Zustand
0V/3,3V

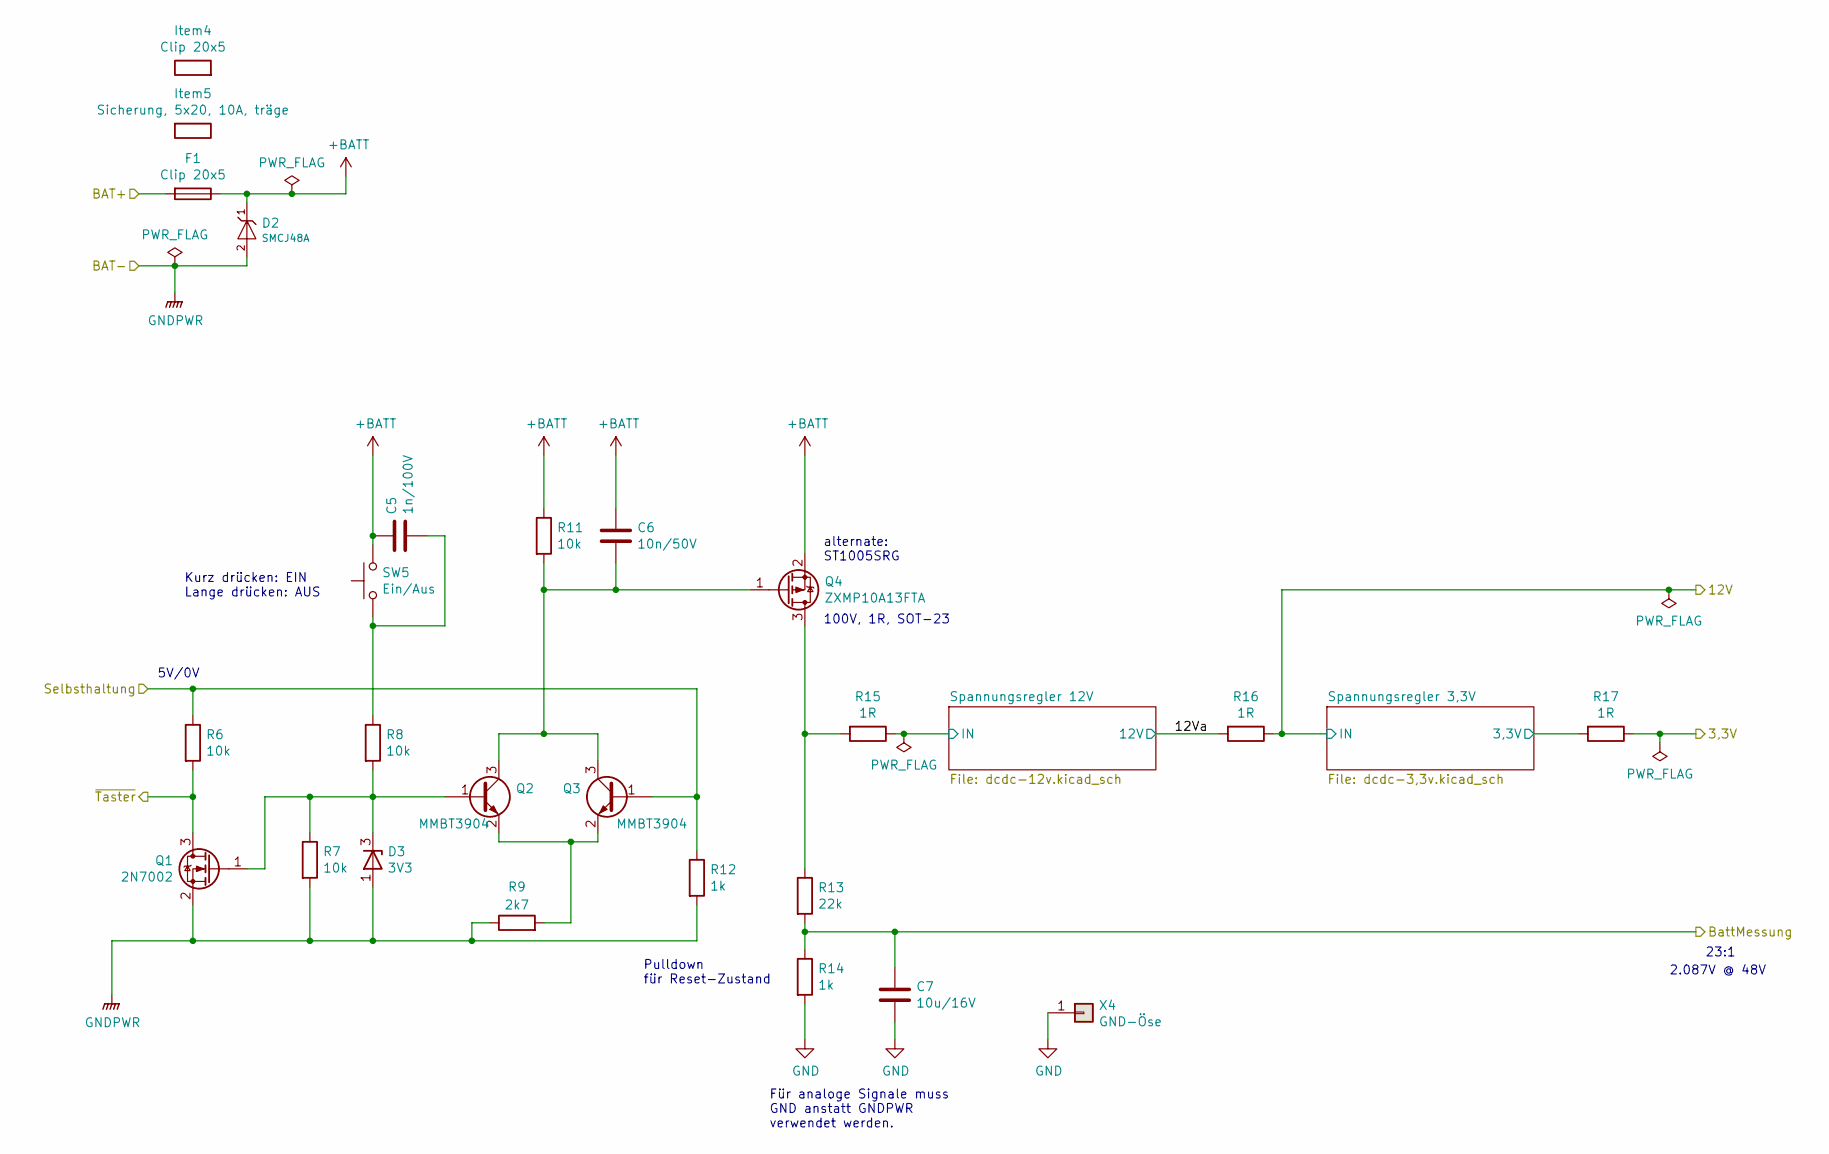
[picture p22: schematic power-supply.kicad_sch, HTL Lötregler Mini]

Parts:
C5: 1n/100V; C_1206_3216Metric; ManPartNr C1206X102K101T
C6: 10n/50V; C_1206_3216Metric; ManPartNr FN31X103K500PXG
C7: 10u/16V; C_1206_3216Metric; ManPartNr CL31B106KOHNNNE
D2: SMCJ48A; D_SMC; ManPartNr SMCJ48A/TR13
D3: 3V3; SOT-23; ManPartNr BZX84-C3V3,235
F1: Clip 20x5; fuse-clip_20x5mm; ManPartNr LS-502
Item4: Clip 20x5; Virtual-Item; ManPartNr LS-502
Item5: Sicherung, 5x20, 10A, träge; Virtual-Item; ManPartNr 0618010.MXP
Q1: 2N7002; SOT-23; ManPartNr 2N7002
Q2, Q3: MMBT3904; SOT-23; ManPartNr MMBT3904
Q4: ZXMP10A13FTA; SOT-23; ManPartNr ZXMP10A13FTA
R6, R7, R8, R11: 10k; R_1206_3216Metric; ManPartNr RS-06K103JT
R9: 2k7; R_1206_3216Metric; ManPartNr RS-06K2701FT
R12, R14: 1k; R_1206_3216Metric; ManPartNr RTT03101JTP
R13: 22k; R_1206_3216Metric
R15, R16, R17: 1R; R_1206_3216Metric; ManPartNr 1206W4F100KT5E
SW5: Ein/Aus; SW_Push_5.1mm_H1.5mm; ManPartNr TS-1187A-B-A-B
X4: GND-Öse; Keystone_5016; ManPartNr 5016

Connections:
+3.3V: R17.1; also elsewhere on the board
+BATT: C5.1, C6.1, D2.1 (K), F1.1, Q4.2 (S), R11.1, SW5.2; also elsewhere on the board
/Arduino/Batteriemessung: C7.1, R13.2, R14.1; also elsewhere on the board
/Arduino/Ein-Aus-Taster: Q1.3 (D), R6.2; also elsewhere on the board
/Arduino/Selbsthaltung: Q3.1 (B), R6.1, R12.1; also elsewhere on the board
/Batterie Varianten/Plus: F1.2; also elsewhere on the board
/Leistungsteil/12V: R16.1; also elsewhere on the board
/Stromversorgung/12Va: R16.2; also elsewhere on the board
/Stromversorgung/Spannungsregler 3,3V/3,3V: R17.2; also elsewhere on the board
/Stromversorgung/Spannungsregler 12V/IN: R15.1; also elsewhere on the board
GND: C7.2, R14.2, X4.1; also elsewhere on the board
GNDPWR: D2.2 (A), D3.1 (A), Q1.2 (S), R7.2, R9.1, R12.2; also elsewhere on the board
unnamed: C5.2, R8.1, SW5.1
unnamed: D3.3 (K), Q1.1 (G), Q2.1 (B), R7.1, R8.2
unnamed: C6.2, Q2.3 (C), Q3.3 (C), Q4.1 (G), R11.2
unnamed: Q2.2 (E), Q3.2 (E), R9.2
unnamed: Q4.3 (D), R13.1, R15.2

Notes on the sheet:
Pulldown für Reset-Zustand
23:1
100V, 1R, SOT-23
2.087V @ 48V
Kurz drücken: EIN Lange drücken: AUS
Für analoge Signale muss GND anstatt GNDPWR verwendet werden.
alternate: ST1005SRG
5V/0V

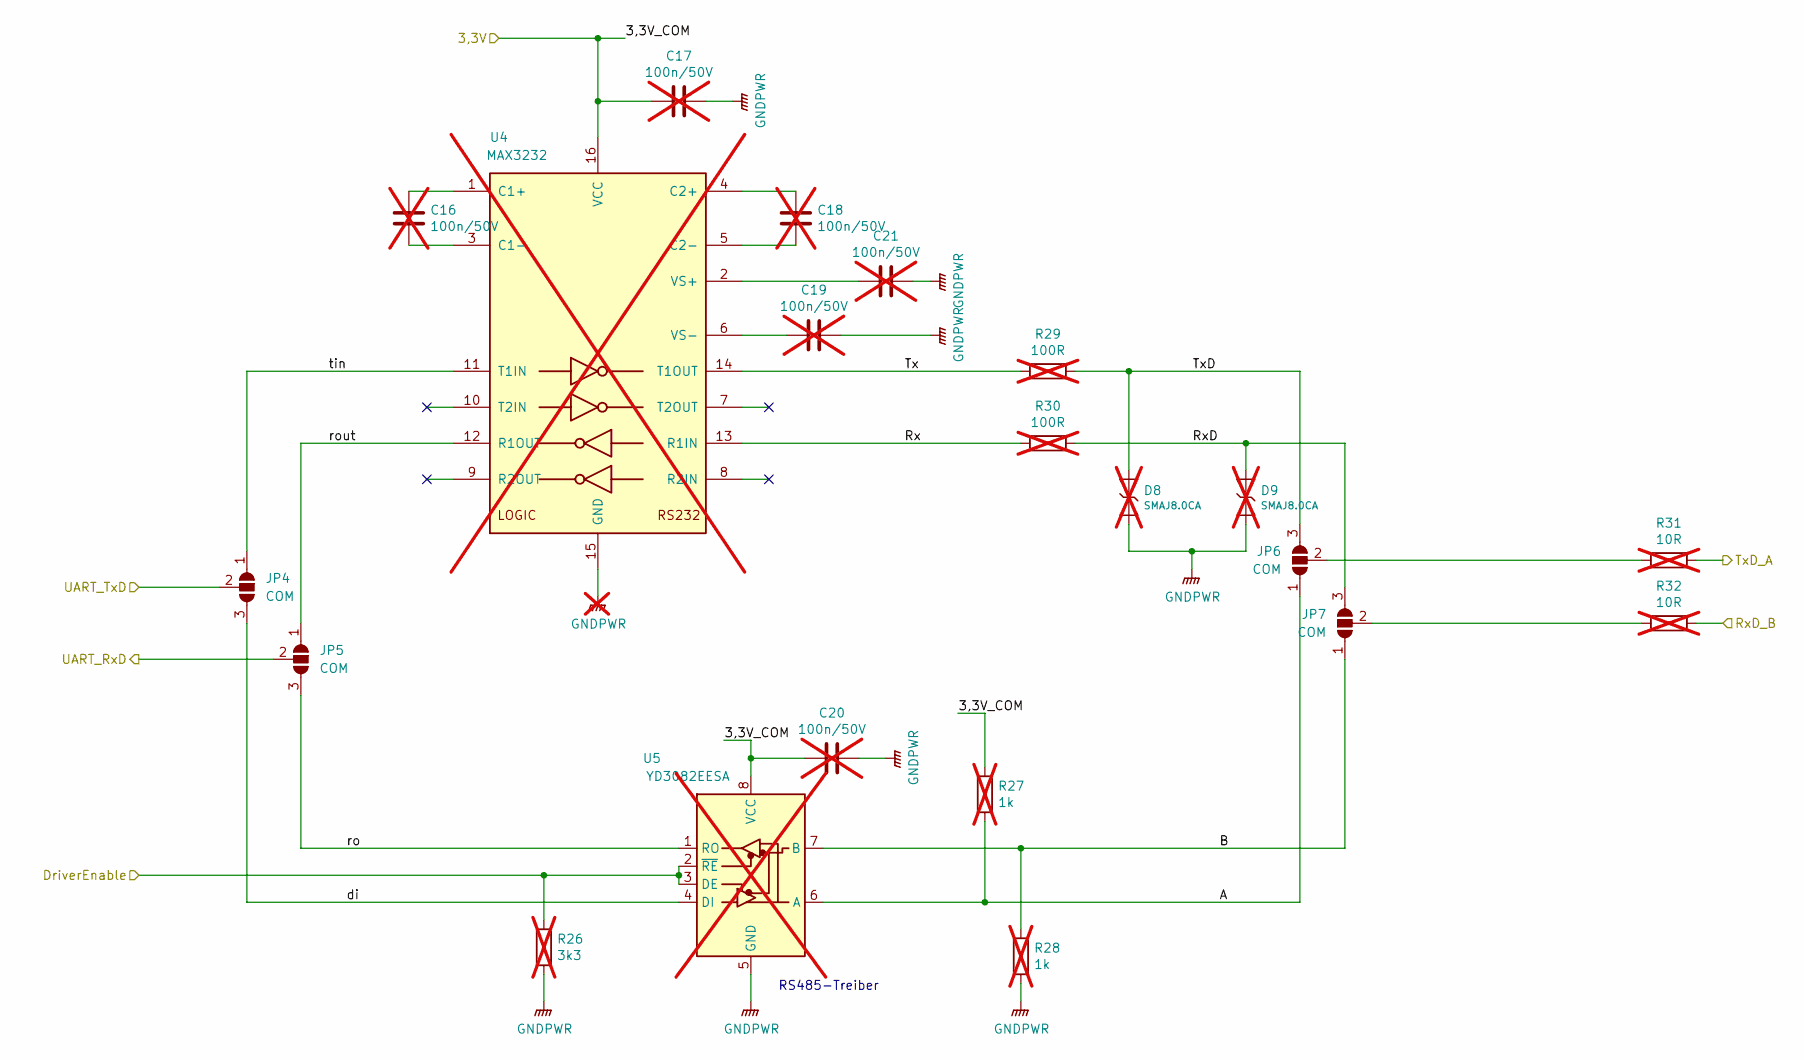
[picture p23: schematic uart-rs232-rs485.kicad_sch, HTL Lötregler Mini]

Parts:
C16, C17, C18, C19, C20, C21: 100n/50V; C_1206_3216Metric; ManPartNr FN31X104K500PXG; not fitted
D8, D9: SMAJ8.0CA; D_SMA; ManPartNr SMAJ8.0CA; not fitted
JP4, JP5, JP6, JP7: COM; SolderJumper-3_P2.0mm_Open_TrianglePad1.0x1.5mm_NumberLabels; ManPartNr NAP
R26: 3k3; R_1206_3216Metric; ManPartNr AC1206FR-073K3L; not fitted
R27, R28: 1k; R_1206_3216Metric; ManPartNr RTT03101JTP; not fitted
R29, R30: 100R; R_1206_3216Metric; ManPartNr CR1206F100RP05Z; not fitted
R31, R32: 10R; R_1206_3216Metric; not fitted
U4: MAX3232; SOIC-16_3.9x9.9mm_P1.27mm; ManPartNr MAX3232EIM/TR; not fitted
U5: YD3082EESA; SOIC-8_3.9x4.9mm_P1.27mm; ManPartNr YD3082EESA; not fitted

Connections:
+3.3V: C17.2, C20.2, R27.1, U4.16 (VCC), U5.8 (VCC); also elsewhere on the board
/Arduino/ComDriverEnable: R26.1, U5.2 (~RE), U5.3 (DE); also elsewhere on the board
/Arduino/RxD: JP5.2 (C); also elsewhere on the board
/Arduino/TxD: JP4.2 (C); also elsewhere on the board
/UART RS232/RS485/A: JP6.1 (A), R27.2, U5.6 (A)
/UART RS232/RS485/B: JP7.1 (A), R28.1, U5.7 (B)
/UART RS232/RS485/Rx: R30.2, U4.13 (R1IN)
/UART RS232/RS485/RxD: D9.1 (A), JP7.3 (B), R30.1
/UART RS232/RS485/RxD_B: R32.1; also elsewhere on the board
/UART RS232/RS485/Tx: R29.2, U4.14 (T1OUT)
/UART RS232/RS485/TxD: D8.1 (A), JP6.3 (B), R29.1
/UART RS232/RS485/TxD_A: R31.1; also elsewhere on the board
/UART RS232/RS485/di: JP4.3 (B), U5.4 (DI)
/UART RS232/RS485/ro: JP5.3 (B), U5.1 (RO)
/UART RS232/RS485/rout: JP5.1 (A), U4.12 (R1OUT)
/UART RS232/RS485/tin: JP4.1 (A), U4.11 (T1IN)
GNDPWR: C17.1, C19.1, C20.1, C21.1, D8.2 (K), D9.2 (K), R26.2, R28.2, U4.15 (GND), U5.5 (GND); also elsewhere on the board
unnamed: JP6.2 (C), R31.2
unnamed: JP7.2 (C), R32.2
unnamed: C16.1, U4.1 (C1+)
unnamed: C16.2, U4.3 (C1-)
unnamed: C18.1, U4.4 (C2+)
unnamed: C18.2, U4.5 (C2-)
unnamed: C21.2, U4.2 (VS+)
unnamed: C19.2, U4.6 (VS-)

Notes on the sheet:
RS485-Treiber

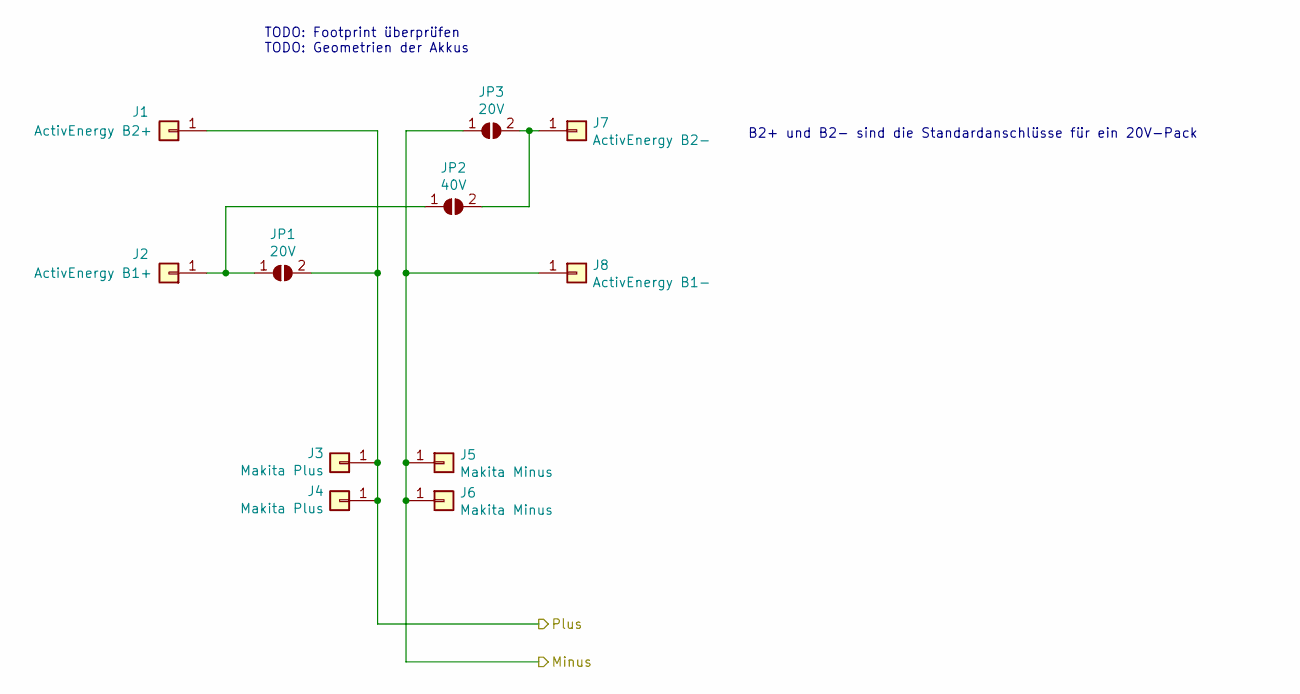
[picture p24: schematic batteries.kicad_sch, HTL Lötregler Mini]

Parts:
J1: ActivEnergy B2+; Faston_Tab_6.3mm_vertical; ManPartNr 03866.A68
J2: ActivEnergy B1+; Faston_Tab_6.3mm_vertical; ManPartNr 03866.A68
J3, J4: Makita Plus; Faston_Tab_6.3mm_vertical; ManPartNr 03866.A68
J5, J6: Makita Minus; Faston_Tab_6.3mm_vertical; ManPartNr 03866.A68
J7: ActivEnergy B2-; Faston_Tab_6.3mm_vertical; ManPartNr 03866.A68
J8: ActivEnergy B1-; Faston_Tab_6.3mm_vertical; ManPartNr 03866.A68
JP1, JP3: 20V; SolderJumper-2_2.2x8mm_Open; ManPartNr NAP
JP2: 40V; SolderJumper-2_2.2x8mm_Open; ManPartNr NAP

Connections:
/Batterie Varianten/Plus: J1.1, J3.1, J4.1, JP1.2 (B); also elsewhere on the board
GNDPWR: J5.1, J6.1, J8.1, JP3.1 (A); also elsewhere on the board
unnamed: J2.1, JP1.1 (A), JP2.1 (A)
unnamed: J7.1, JP2.2 (B), JP3.2 (B)

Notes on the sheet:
TODO: Footprint überprüfen TODO: Geometrien der Akkus
B2+ und B2- sind die Standardanschlüsse für ein 20V-Pack

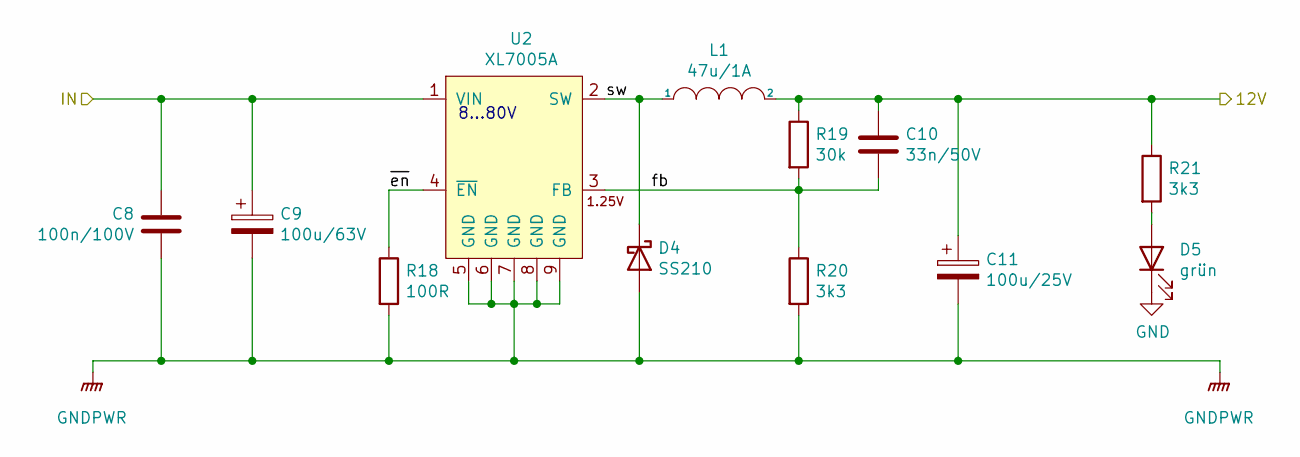
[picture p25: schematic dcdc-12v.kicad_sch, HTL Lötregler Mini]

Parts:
C8: 100n/100V; C_1206_3216Metric; ManPartNr CL31B104KCFNNNE
C9: 100u/63V; CP_Elec_8x10; ManPartNr VKMD1001J101MV
C10: 33n/50V; C_1206_3216Metric; ManPartNr TCC1206X7R333K500DT
C11: 100u/25V; CP_Elec_6.3x5.9; ManPartNr SVZ1EM101E06E00RAXXX
D4: SS210; D_SMA_wide; ManPartNr SS210A-W
D5: grün; LED_1206_3216Metric; ManPartNr XL-3216UGC
L1: 47u/1A; L_7.3x7.3_H4.5_C216198; ManPartNr SLH0704S470MTT
R18: 100R; R_1206_3216Metric; ManPartNr CR1206F100RP05Z
R19: 30k; R_1206_3216Metric; ManPartNr RC1206FR-0730KL
R20, R21: 3k3; R_1206_3216Metric; ManPartNr AC1206FR-073K3L
U2: XL7005A; SOIC-8-1EP_3.9x4.9mm_P1.27mm_EP2.514x3.2mm_ThermalVias; ManPartNr XL7005A

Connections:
/Stromversorgung/12Va: C10.1, C11.1, L1.2, R19.1, R21.1; also elsewhere on the board
/Stromversorgung/Spannungsregler 12V/IN: C8.1, C9.1, U2.1 (VIN); also elsewhere on the board
/Stromversorgung/Spannungsregler 12V/fb: C10.2, R19.2, R20.1, U2.3 (FB)
/Stromversorgung/Spannungsregler 12V/sw: D4.1 (K), L1.1, U2.2 (SW)
/Stromversorgung/Spannungsregler 12V/~en: R18.1, U2.4 (~EN)
GND: D5.1 (K); also elsewhere on the board
GNDPWR: C8.2, C9.2, C11.2, D4.2 (A), R18.2, R20.2, U2.5 (GND), U2.6 (GND), U2.7 (GND), U2.8 (GND), U2.9 (GND); also elsewhere on the board
unnamed: D5.2 (A), R21.2

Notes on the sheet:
8...80V

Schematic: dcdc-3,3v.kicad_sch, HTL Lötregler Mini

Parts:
C12: 100n/100V; C_1206_3216Metric; ManPartNr CL31B104KCFNNNE
C13, C15: 100u/25V; CP_Elec_6.3x5.9; ManPartNr SVZ1EM101E06E00RAXXX
C14: 33n/50V; C_1206_3216Metric; ManPartNr TCC1206X7R333K500DT
D6: SS210; D_SMA_wide; ManPartNr SS210A-W
D7: grün; LED_1206_3216Metric; ManPartNr XL-3216UGC
L2: 47u/1A; L_7.3x7.3_H4.5_C216198; ManPartNr SLH0704S470MTT
R22: 100R; R_1206_3216Metric; ManPartNr CR1206F100RP05Z
R23: 10k; R_1206_3216Metric; ManPartNr RS-06K103JT
R24: 6k2; R_1206_3216Metric; ManPartNr RS-06K6191FT
R25: 680R; R_1206_3216Metric; ManPartNr RS-06K681JT
U3: XL7005A; SOIC-8-1EP_3.9x4.9mm_P1.27mm_EP2.514x3.2mm_ThermalVias; ManPartNr XL7005A

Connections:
/Leistungsteil/12V: C12.1, C13.1, U3.1 (VIN); also elsewhere on the board
/Stromversorgung/Spannungsregler 3,3V/3,3V: C14.1, C15.1, L2.2, R23.1, R25.1; also elsewhere on the board
/Stromversorgung/Spannungsregler 3,3V/fb: C14.2, R23.2, R24.1, U3.3 (FB)
/Stromversorgung/Spannungsregler 3,3V/sw: D6.1 (K), L2.1, U3.2 (SW)
/Stromversorgung/Spannungsregler 3,3V/~en: R22.1, U3.4 (~EN)
GND: D7.1 (K); also elsewhere on the board
GNDPWR: C12.2, C13.2, C15.2, D6.2 (A), R22.2, R24.2, U3.5 (GND), U3.6 (GND), U3.7 (GND), U3.8 (GND), U3.9 (GND); also elsewhere on the board
unnamed: D7.2 (A), R25.2

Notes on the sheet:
8...80V

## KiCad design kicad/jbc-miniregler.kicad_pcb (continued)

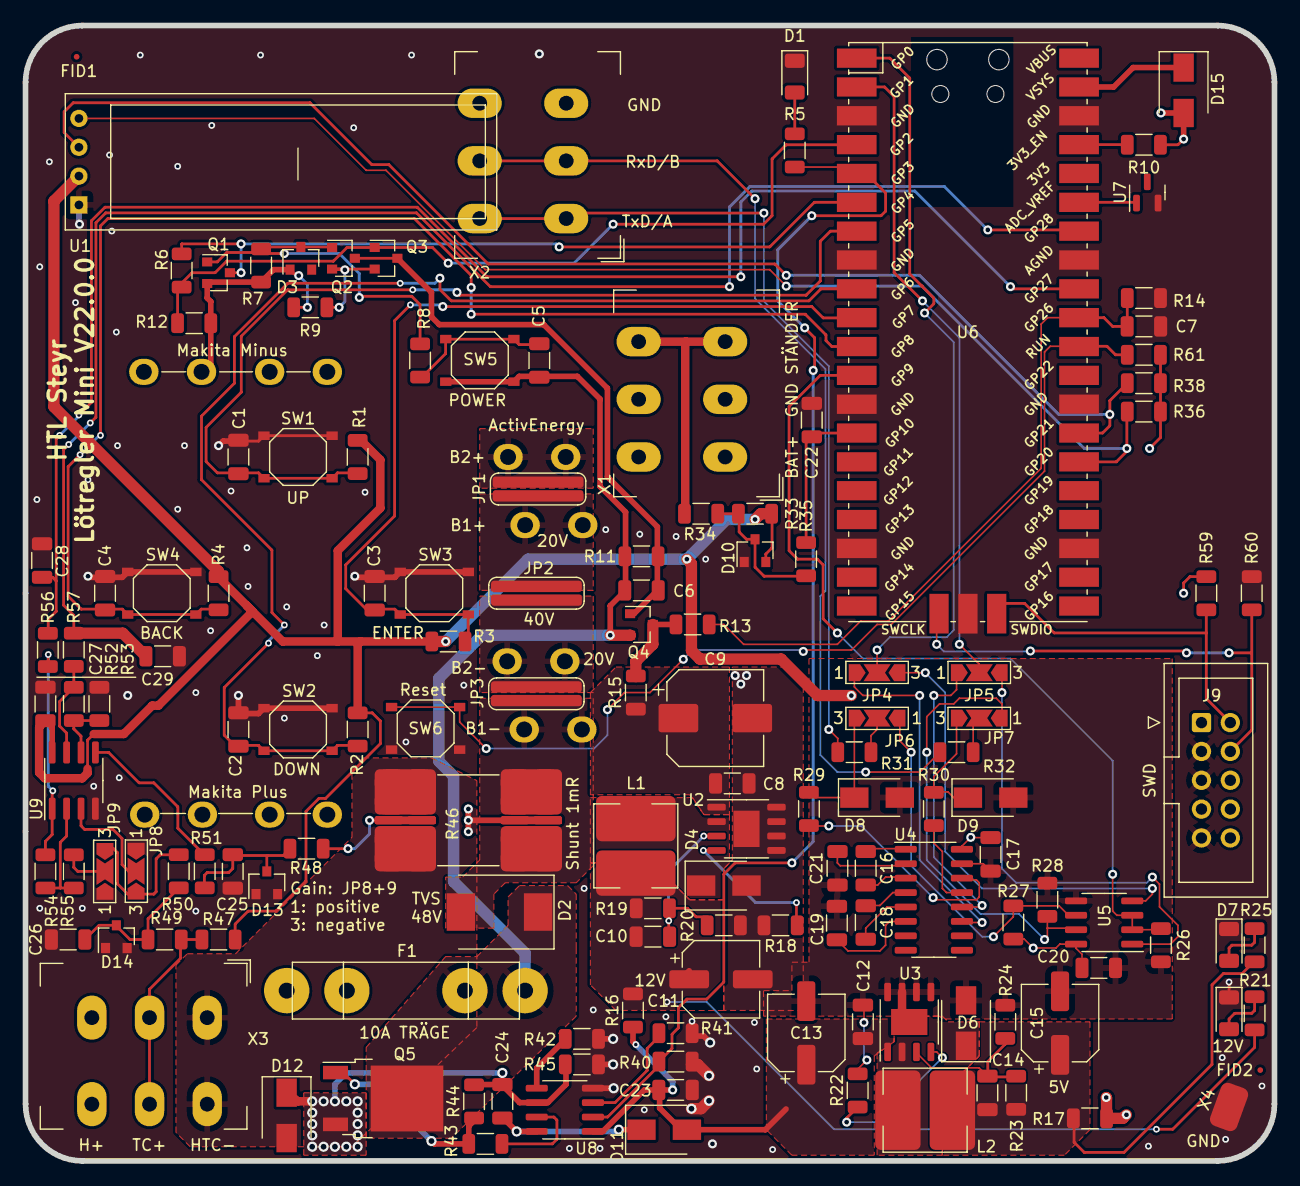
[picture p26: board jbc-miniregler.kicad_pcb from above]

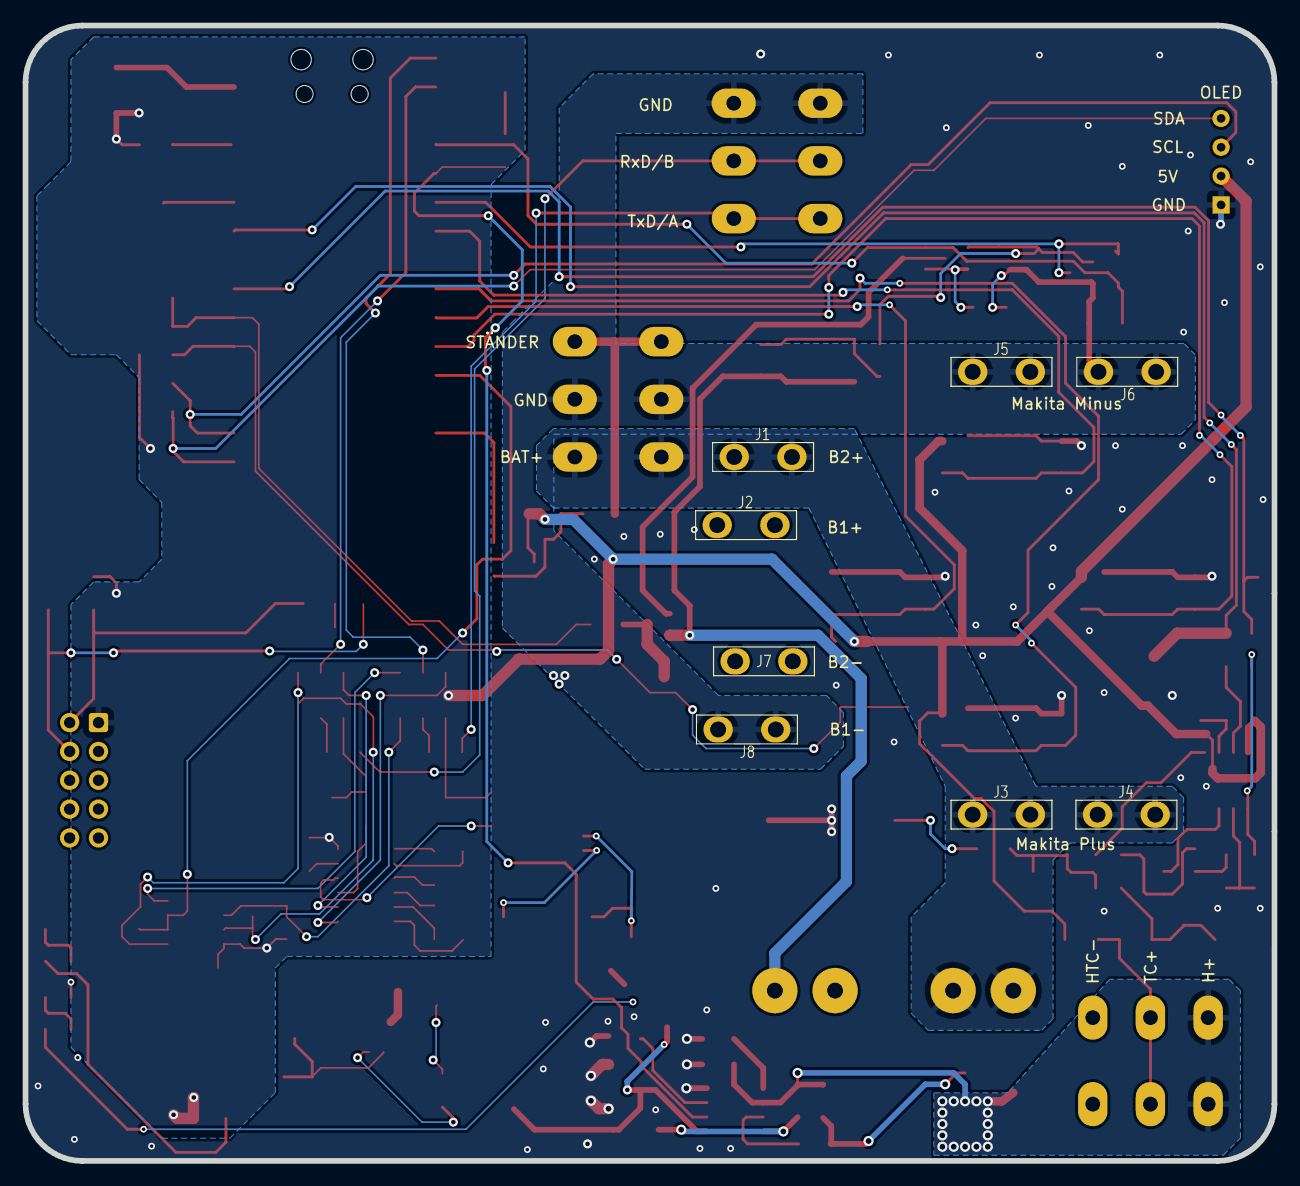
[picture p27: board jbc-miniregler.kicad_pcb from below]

Board: 2 copper layers, 110.0 x 100.0 mm, 154 parts (8 on the bottom side), 88 nets.

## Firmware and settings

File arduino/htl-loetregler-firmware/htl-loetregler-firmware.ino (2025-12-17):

#include <stdlib.h>
#include <time.h>
#include <SPI.h>
#include <Wire.h>
#include <Adafruit_GFX.h>
#include <Adafruit_SSD1306.h>
#include "button.h"


// Declaration for an SSD1306 display connected to I2C (SDA, SCL pins)
#define SCREEN_WIDTH 128 // OLED display width, in pixels
#define SCREEN_HEIGHT 32 // OLED display height, in pixels
#define OLED_RESET     -1 // Reset pin # (or -1 if sharing Arduino reset pin)
Adafruit_SSD1306 display(SCREEN_WIDTH, SCREEN_HEIGHT, &Wire, OLED_RESET);


#define PIN_Selbsthaltung   2
#define PIN_Heizelement     3
// Taster, siehe button.cpp
#define PIN_ComTreiber_Enable   9

#ifdef __AVR__

// Externe Referenzspannung 2.51V +/-0.5%
#define PIN_AIN_UBatt       A0
#define PIN_AIN_TempSensor  A1
#define PIN_AIN_Strom       A2
// A3: unused
// A4: SDA (OLED und PCB-Temp-Sensor)
// A5: SCL (OLED und PCB-Temp-Sensor)
#define PIN_AIN_Staender    A6

#else

// Externe Referenzspannung 3.00V +/-0.5%
#define PIN_AIN_UBatt       A0
#define PIN_AIN_TempSensor  A1
#define PIN_AIN_Strom       A2
// TODO
// A3: unused
// A4: SDA (OLED und PCB-Temp-Sensor)
// A5: SCL (OLED und PCB-Temp-Sensor)
//#define PIN_AIN_Staender    A6

#endif

#define DIVISOR 2
#define SPANNUNG_VOLL (40.0/DIVISOR)
#define SPANNUNG_LEER (32.0/DIVISOR)

#define MIT_NAMEN
#define VORNAME  "Franz"
#define NACHNAME "Reithuber"
#define VERSION "0.2" // max. 3 characters!

#define STROMWERTE 100

char str[20] = {0};
uint16_t tempSoll = 50;
uint16_t tempSpitze = 999;
bool standby = false;
bool forcedShutdown = false;
uint32_t timeLastTempIncrease = 0;
float power = 0;
float uBatt = 0;


enum Screen {BootScreen, MainScreen, ShutdownScreen} activeScreen = BootScreen;

void setup() {
  pinMode(PIN_Selbsthaltung, OUTPUT);
  selbsthaltung();

  // put your setup code here, to run once:

#if defined(__AVR__)
  analogReference(EXTERNAL); // 2.51V
  // RPi Pico uses external 3.0V reference
#endif

  Serial.begin(115200);
  delay(100);
  Serial.println("HTL LOETREGLER MINI");

  #if !defined(__AVR__)
    #define WIRE_SDA 20;
    #define WIRE_SCL 21;
  #endif
  Wire.begin();

  // SSD1306_SWITCHCAPVCC = generate display voltage from 3.3V internally
  if (!display.begin(SSD1306_SWITCHCAPVCC, 0x3c, false, false)) {
    Serial.println(F("SSD1306 allocation failed"));
    for (;;); // Don't proceed, loop forever
  }

  display.clearDisplay();
  display.setTextSize(2);
  display.setTextColor(WHITE);
  display.display();
  delay(500);

  pinMode(PIN_Heizelement, OUTPUT);
  analogWrite(PIN_Heizelement, 3);
}

void showBanner() {
  display.clearDisplay();
  display.setCursor(10, 0);
  display.setTextSize(2);
  display.setTextColor(WHITE);
  display.print("HTL STEYR");
#if defined(__AVR__)
  display.setCursor(0, 31 - 7 - 8);
  display.setTextSize(1);
  display.print("LOETREGLER MINI V" VERSION);
  display.setCursor(0, 31 - 7);
  display.setTextSize(1);
  display.print(" ARDUINO NANO");
#else
  display.setCursor(0, 31 - 7 - 8);
  display.setTextSize(1);
  display.print("LOETREGLER MINI V" VERSION);
  display.setCursor(0, 31 - 7);
  display.setTextSize(1);
  display.print(" RASPBERRY PI PICO");
#endif
  display.display();

  delay(2000);

#ifdef MIT_NAMEN
  nameAnzeigen();
#endif
}

void nameAnzeigen() {
  display.clearDisplay();
  display.setCursor(0, 0);
  display.setTextSize(2);
  display.setTextColor(WHITE);
  display.print(VORNAME);
  display.setCursor(0, 31 - 14);
  display.setTextSize(2);
  display.print(NACHNAME);
  display.display();

  delay(1000);
}

void mainScreen() {
  static const int8_t UpdatePeriod = 3;
  static int8_t updateCounter = UpdatePeriod;
  // paint static objects

  if (activeScreen != MainScreen) {
    updateCounter = 0;
    activeScreen = MainScreen;
    display.clearDisplay();

    // Grad Celsius groß
    display.setTextSize(3);
    display.setCursor(60, 1);
    display.print("C");
    display.drawCircle(57, 3, 2, WHITE);
    display.drawCircle(57, 3, 3, WHITE);


    // Watt
    display.setTextSize(1);
    display.setCursor(2 + 3 * 6, 24);
    display.print("W");

    // Grad Celsius klein
    display.setTextSize(1);
    display.setCursor(59, 24);
    display.print("C");
    display.drawCircle(56, 25, 1, WHITE);

    // Volt
    display.setTextSize(1);
    display.setCursor(96 + 4 * 6, 18);
    display.print("V");

    // Batterieumrandung
    display.drawRect(96, 3, 27, 11, WHITE);
    display.drawRect(122, 6, 3, 5, WHITE);
  }

  // CLEAR Dynamic Objects
  {
    updateCounter--;
    if (updateCounter <= 0) {
      display.fillRect(2, 1, 3 * 18 - 3, 21, BLACK); // Ist-Temp.
    }
    display.fillRect(2, 24, 3 * 6 - 1, 7, BLACK); // Leistung
    display.fillRect(36, 24, 3 * 6 - 1, 7, BLACK); // Soll Temperatur
    display.fillRect(96, 18, 4 * 6 - 1, 7, BLACK); // Batterie Spannung
    display.fillRect(98, 5, 2 * 12 - 1, 7, BLACK); // Batterie Zustand
  }


  // Draw/Print Dynamic Objects:
  {
    // Ist Temperatur
    //tempSpitze = temperaturSpitze();
    // tempSpitze wird aus regler() übernommen
    static int32_t sumTemp = 0;
    sumTemp += tempSpitze;
    if (updateCounter <= 0) {
      display.setCursor(2, 1);
      display.setTextSize(3);
      sprintf(str, "%d", uint16_t(sumTemp / UpdatePeriod));
      display.print(str);
      sumTemp = 0;
    }

    // Soll Temperatur
    display.setCursor(36, 24);
    display.setTextSize(1);
    sprintf(str, "%d", uint16_t(tempSoll));
    display.print(str);

    // Batteriespannung
    uBatt = spannungBatterie();
    display.setTextSize(1);
    sprintf(str, "%3d", uint16_t(uBatt * 10));
    display.setCursor(96, 18);
    display.print(str[0]);
    display.setCursor(96 + 6, 18);
    display.print(str[1]);
    display.setCursor(96 + 12, 18);
    display.print(".");
    display.setCursor(96 + 18, 18);
    display.print(str[2]);

    uint8_t z = (batterieZustand() * 12 + 50) / 100; // umrechnen auf 12 Skalenstriche
    for (int x = 0; x < z; x++) {
      display.drawLine(x * 2 + 98, 5, x * 2 + 98, 11, WHITE);
    }

    // Leistung
    display.setCursor(2, 24);
    display.setTextSize(1);
    sprintf(str, "%d", uint16_t(power));
    display.print(str);
  }

  if (updateCounter <= 0) {
    updateCounter = UpdatePeriod;
  }
  display.display();
}

// 0...100%
uint8_t batterieZustand() {
  int32_t ret = constrain(
                  100.0 / (SPANNUNG_VOLL - SPANNUNG_LEER) * (spannungBatterie() - SPANNUNG_LEER),
                  0, 100);
  Serial.println(ret);
  return ret;
}

void regler() {
  static float stromMesswerte[STROMWERTE] = {0};
  static float strommittel;
  float stromsumme = 0;
  static uint8_t dutycycle = 250;
  static uint8_t cnt = 0;
  static bool full = false;

  tempSpitze = temperaturSpitze();
  if ((!standby && (tempSpitze < tempSoll)) || (standby && (tempSpitze < 150))) {
    dutycycle = 250;
    analogWrite(PIN_Heizelement, dutycycle); // nicht 100% PWM (=255), damit der Bootstrap-Kondensator nachladen kann!
  } else {
    dutycycle = 250;
  }

  if (tempSpitze + 80 < tempSoll) {
    // beschleunigtes Heizen
    delay(50);
  } else {
    delay(10); // max. 10ms durchgehend Heizen
  }

  stromMesswerte[cnt] = strom();

  if (cnt > STROMWERTE - 1) {
    if (!full) {
      full = true;
    }
    cnt = 0;
  } else {
    cnt++;
  }

  for (int i = 0; i < STROMWERTE; i++) {
    stromsumme = stromsumme + stromMesswerte[i];
  }
  if (full) {
    strommittel = stromsumme / STROMWERTE;
  } else {
    strommittel = stromsumme / (cnt + 1);
  }

  power = ((uBatt * dutycycle) / 255) * strommittel;

  analogWrite(PIN_Heizelement, 0);
}

void tasterAuswertung() {
  buttons.readAll();
  if (buttons.up->getEvent() == Button::PressedEvent) {
    tempSoll += 10;
    timeLastTempIncrease = millis();
  }
  if (buttons.down->getEvent() == Button::PressedEvent) {
    tempSoll -= 10;
  }
  if (buttons.back->getEvent() == Button::PressedEvent) {
    standby = true;
  }
  if (buttons.enter->getEvent() == Button::PressedEvent) {
    standby = false;
  }
  if ((buttons.power->getEvent() == Button::PressedEvent) && millis() > 1000) {
    abschalten();
  }
  tempSoll = constrain(tempSoll, 50, 450);
}

void loop() {
  mainScreen();
  regler();
  tasterAuswertung();
  selbsthaltung();
  zeitabschaltung();
  uebertemperaturwaechter();
}

// Temperaturen über 330°C werden nur 1 Minute zugelassen
// Dient dem Schutz des 3D-gedruckten Griffstücks
void uebertemperaturwaechter()
{
  if (millis() > timeLastTempIncrease + 60000UL && tempSoll > 330) {
    tempSoll = 80;
  }
}

float spannungMessen(uint8_t pin) {
  float u = analogRead(pin);
#if defined(__AVR__)
  u = u * 2.51 / 1024;
#else
  u = u * 3.00 / 1024;
#endif
  return u;
}

// muss periodisch aufgerufen werden!
void selbsthaltung() {
  if (millis() < 10000 || spannungBatterie() > SPANNUNG_LEER) { // für 40V-Akku: 30V, für 20V-Akku: 15V
    digitalWrite(PIN_Selbsthaltung, HIGH);
  } else {
    Serial.println("Unterspannung");
    forcedShutdown = true;
    abschalten();
  }
}

float temperaturSpitze() {
  return spannungMessen(PIN_AIN_TempSensor) / 221 / 24e-6 + 30; // in °C
}

float spannungBatterie() {
  return spannungMessen(PIN_AIN_UBatt) * 23;
}

float strom() {
  return spannungMessen(PIN_AIN_Strom) / 221 / 0.001;
}

// muss periodisch aufgerufen werden
void zeitabschaltung() {
  if (millis() / 1000 / 60 > 10) {
    Serial.println("Zeitabschaltung");
    abschalten();
  }
}

// doesn't return any more, except, if powered by USB
void abschalten() {
  if (digitalRead(10) == HIGH) {
    digitalWrite(PIN_Selbsthaltung, LOW);
    return;
  }

  showBanner();

  display.fillRect(0, 0, 128, 32, BLACK);
  display.setTextSize(1);
  display.setCursor(0, 0);
  display.print("ACHTUNG HEISS");
  display.setCursor(0, 10);
  display.print("AUSKUEHLEN...");
  display.display();

  bool reActivate = false;
  activeScreen = ShutdownScreen;
  while (!(temperaturSpitze() < 60 || temperaturSpitze() > 490 || (reActivate && !forcedShutdown))) {
    display.fillRect(0, 20, 128, 10, BLACK);
    display.setCursor(0, 20);
    sprintf(str, "%d", uint16_t(temperaturSpitze()));
    display.print(str);
    display.display();
    uint32_t currentTime = millis();
    while (millis() < currentTime + 1000) {
      buttons.readAll();
      if ((buttons.power->getEvent() == Button::PressedEvent)) {
        reActivate = true;
      }
      if (temperaturSpitze() >= 490) {
        forcedShutdown = true;
      }
    }
  }
  display.clearDisplay();
  if (!reActivate) {
    digitalWrite(PIN_Selbsthaltung, LOW);
    while (1);
  }

}

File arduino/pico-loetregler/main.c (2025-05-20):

// main.c
#include <stdio.h>
#include <stdlib.h>
#include "pico/stdlib.h"
#include "hardware/adc.h"
#include "hardware/i2c.h"
#include "hardware/pwm.h"
#include "ssd1306.h"
#include "button.h"

#define SCREEN_WIDTH 128
#define SCREEN_HEIGHT 32

#define I2C_PORT i2c0
#define I2C_SDA_PIN 4
#define I2C_SCL_PIN 5

#define PIN_SELBSHALTUNG 2
#define PIN_HEIZELEMENT 3
#define PIN_COMTREIBER_ENABLE 9

#define ADC_UBATT 0  // GPIO26
#define ADC_TEMPSENSOR 1 // GPIO27
#define ADC_STROM 2 // GPIO28

#define DIVISOR 2.0f
#define SPANNUNG_VOLL (40.0f / DIVISOR)
#define SPANNUNG_LEER (32.0f / DIVISOR)

#define PWM_FREQ 20000 // 20 kHz
#define MAX_DUTY_CYCLE 0.8f // 80%

static ssd1306_t display;

uint16_t tempSoll = 30;
uint16_t tempSpitze = 999;
bool standby = false;
bool forcedShutdown = false;
uint32_t timeLastTempIncrease = 0;
float power = 0;
float uBatt = 0;

void selbsthaltung() {
    gpio_put(PIN_SELBSHALTUNG, 1);
}

float read_adc_voltage(uint adc_channel) {
    adc_select_input(adc_channel);
    uint16_t raw = adc_read();
    return raw * 3.0f / 4095.0f;
}

void init_display() {
    i2c_init(I2C_PORT, 400 * 1000);
    gpio_set_function(I2C_SDA_PIN, GPIO_FUNC_I2C);
    gpio_set_function(I2C_SCL_PIN, GPIO_FUNC_I2C);
    gpio_pull_up(I2C_SDA_PIN);
    gpio_pull_up(I2C_SCL_PIN);
    ssd1306_init(&display, I2C_PORT, 0x3C, SCREEN_WIDTH, SCREEN_HEIGHT);
    ssd1306_clear(&display);
    ssd1306_draw_string(&display, 0, 0, 1, "HTL LOETREGLER MINI");
    ssd1306_show(&display);
}

void init_pwm() {
    gpio_set_function(PIN_HEIZELEMENT, GPIO_FUNC_PWM);
    uint slice_num = pwm_gpio_to_slice_num(PIN_HEIZELEMENT);
    pwm_set_wrap(slice_num, 1250); // 20 kHz frequency
    pwm_set_enabled(slice_num, true);
}

void set_pwm_duty_cycle(float duty_cycle) {
    if (duty_cycle > MAX_DUTY_CYCLE) {
        duty_cycle = MAX_DUTY_CYCLE;
    }
    uint slice_num = pwm_gpio_to_slice_num(PIN_HEIZELEMENT);
    uint16_t level = duty_cycle * 1250;
    pwm_set_gpio_level(PIN_HEIZELEMENT, level);
}

void control_heating(float temp) {
    float temp_diff = tempSoll - temp;
    float duty_cycle = temp_diff / tempSoll;
    set_pwm_duty_cycle(duty_cycle);
}

int main() {
    stdio_init_all();
    gpio_init(PIN_SELBSHALTUNG);
    gpio_set_dir(PIN_SELBSHALTUNG, GPIO_OUT);
    gpio_init(PIN_COMTREIBER_ENABLE);
    gpio_set_dir(PIN_COMTREIBER_ENABLE, GPIO_OUT);

    adc_init();
    adc_gpio_init(26);
    adc_gpio_init(27);
    adc_gpio_init(28);

    button_init();
    init_display();
    init_pwm();
    selbsthaltung();

    while (true) {
        button_update();

        if (button_pressed(BUTTON_UP)) {
            tempSoll += 10;
            timeLastTempIncrease = to_ms_since_boot(get_absolute_time());
        }

        if (button_pressed(BUTTON_DOWN)) {
            tempSoll -= 10;
        }

        float temp = read_adc_voltage(ADC_TEMPSENSOR) * 100.0f;
        uBatt = read_adc_voltage(ADC_UBATT) * (40.0f / 3.0f);

        control_heating(temp);

        ssd1306_clear(&display);
        char buffer[32];
        snprintf(buffer, sizeof(buffer), "Temp: %.1f / %d", temp, tempSoll);
        ssd1306_draw_string(&display, 0, 0, 1, buffer);
        snprintf(buffer, sizeof(buffer), "U: %.2fV", uBatt);
        ssd1306_draw_string(&display, 0, 10, 1, buffer);
        ssd1306_show(&display);

        sleep_ms(200);
    }
    return 0;
}

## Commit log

2024-07-12 created bom for order lcsc
    [Bom-calc.ods, amplifier.kicad_sch, batteries.kicad_sch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]
2024-12-23 umstellung auf pico als Main
    [Bestellung LCSC 2023-02-15.ods, Bestellung LCSC 2023-02-15.xls, Deckel_ohne_reset.3mf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]
2024-12-30 .ino anpassung fehler mit ! bei I2C
2025-03-23 Rewrite of Firmware for rp2040
    Started with the new Firmware not funktional jet
    [1306_i2c.fzz]
2025-05-25 arduino update
2025-12-15 Case Update
    [blindstopfen_v1.3mf, gehäuse-boden_v0.stl, lötregler-gehäuse-boden_v1.stl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]
